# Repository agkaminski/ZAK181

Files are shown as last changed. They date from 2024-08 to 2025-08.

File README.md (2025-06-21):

# ZAK181 computer

Work in progress.

## Hardware features

- Z180 CPU,
- 1 MB of static RAM,
- 16 KB bootloader ROM,
- Comact Flash slot in True IDE mode,
- 16 bit GPIO user port,
- 2 UARTs: USB-C and RS232,
- AY-3-8912 sound,
- 80x60 8-color text mode VGA output,
- custom Cherry-MX mechanical keyboard,
- USB-C powered.

## Firmare

ZAKOS code repository is located [here](https://github.com/agkaminski/ZAKOS).

## Memory map

| Start | End | Description |
|---|---|---|
| 0x00000 | 0x03FFF | ROM, disabled after boot, after that RAM |
| 0x04000 | 0xFDFFF | RAM |
| 0xFC000 | 0xFFFFF | Memory mapped I/O, VGA VRAM |

## I/O map

8-bit I/O is used.

| Start | End  | Description |
|---|---|---|
| 0x00  | 0x3F | Z180 internal I/O |
| 0x40  | 0x5F | VBLANK IRQ acknowledge |
| 0x60  | 0x7F | ROM disable control |
| 0x80  | 0x9F | Keyboard |
| 0xA0  | 0xBF | Z80 PIO (user port) |
| 0xC0  | 0xDF | AY-3-8912 |
| 0xE0  | 0xFF | Compact Flash |

## Repository structure

### datasheet

Collection of useful datasheets, might be removed in the future.

### keyboard2

Subrepository that contains a hardware project of a mechanical keyboard for the
computer.

### kicad

KiCAD project of the computer's PCB.

### pld

Gateware of PLDs:

- [vga](pld/vga/README.md),
- [ZAK181MD](pld/ZAK181MD/README.md),
- [ZAK181AY](pld/ZAK181AY/README.md).

### schematic.pdf

[Schematic](schematic.pdf) of the computer in a friendly .pdf form.

### 3dprint

3D models designed for FDM 3D priting.

## License

[Attribution-NonCommercial 4.0](LICENSE)

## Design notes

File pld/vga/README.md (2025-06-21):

# CPLD - VGA timing generator and position counter

Target: XC95108, any speed, **not** XL version

## Pinout

| Pin | Type | Name |
|-----|---|---|
| 1 | I/O | vdata<3>  |
| 2 | I/O | vdata<4>  |
| 3 | I/O | vdata<5>  |
| 4 | I/O | vdata<6>  |
| 5 | I/O | vdata<7>  |
| 6 | I/O | vaddr<10> |
| 7 | I/O | vrd_n |
| 8 | GND | GND |
| 9 | I/O/GCK1 | pclk |
| 10  | I/O/GCK2 | TIE |
| 11  | I/O | vaddr<11> |
| 12  | I/O/GCK3 | shload_n  |
| 13  | I/O | vaddr<9>  |
| 14  | I/O | vaddr<8>  |
| 15  | I/O | vaddr<13> |
| 16  | GND | GND |
| 17  | I/O | vwr_n |
| 18  | I/O | vaddr<12> |
| 19  | I/O | vaddr<7>  |
| 20  | I/O | vaddr<6>  |
| 21  | I/O | vaddr<5>  |
| 22  | VCCIO | VCC |
| 23  | I/O | vaddr<4>  |
| 24  | I/O | vaddr<3>  |
| 25  | I/O | vaddr<2>  |
| 26  | I/O | vaddr<1>  |
| 27  | GND | GND |
| 28  | TDI | TDI |
| 29  | TMS | TMS |
| 30  | TCK | TCK |
| 31  | I/O | vaddr<0>  |
| 32  | I/O | vdata<0>  |
| 33  | I/O | vdata<2>  |
| 34  | I/O | vdata<1>  |
| 35  | I/O | scroll<0> |
| 36  | I/O | scroll<1> |
| 37  | I/O | scroll<2> |
| 38  | VCCINT | VCC |
| 39  | I/O | scroll<3> |
| 40  | I/O | scroll<4> |
| 41  | I/O | scroll<5> |
| 42  | GND | GND |
| 43  | I/O | irqack_n  |
| 44  | I/O | irq_n |
| 45  | I/O | data<3> |
| 46  | I/O | data<2> |
| 47  | I/O | data<4> |
| 48  | I/O | data<1> |
| 49  | GND | GND |
| 50  | I/O | data<5> |
| 51  | I/O | data<0> |
| 52  | I/O | data<6> |
| 53  | I/O | data<7> |
| 54  | I/O | crow<2> |
| 55  | I/O | crow<1> |
| 56  | I/O | crow<0> |
| 57  | I/O | addr<12>  |
| 58  | I/O | addr<11>  |
| 59  | TDO | TDO |
| 60  | GND | GND |
| 61  | I/O | addr<13>  |
| 62  | I/O | addr<9> |
| 63  | I/O | addr<10>  |
| 64  | VCCIO | VCC |
| 65  | I/O | addr<7> |
| 66  | I/O | addr<8> |
| 67  | I/O | addr<5> |
| 68  | I/O | addr<6> |
| 69  | I/O | addr<4> |
| 70  | I/O | addr<2> |
| 71  | I/O | addr<3> |
| 72  | I/O | addr<0> |
| 73  | VCCINT | VCC |
| 74  | I/O/GSR  | rst_n |
| 75  | I/O | addr<1> |
| 76  | I/O/GTS1 | blank |
| 77  | I/O/GTS2 | rd_n |
| 78  | VCCINT | VCC |
| 79  | I/O | wr_n |
| 80  | I/O | cs_n |
| 81  | I/O | hsync_n |
| 82  | I/O | vsync_n |
| 83  | I/O | pload_n |
| 84  | I/O | cload_n |

## vga.v

Implementation (Verilog).

## vga.dig

Test bench of sorts - uses [Digital](https://github.com/hneemann/Digital), which has a
huge advantage over plain Verilog/VHDL based test bench - it can process generated VGA
data and present it visually. It makes it a perfect tool for this kind of verification.

## vga.ucf

Pinout constraints (ISE 14.7).

## vga.jed

Bitstream ready to upload to the CPLD.

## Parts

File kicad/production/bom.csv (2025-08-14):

Designator | Footprint | Quantity | Value | LCSC Part #
C10, C11, C12, C13, C16, C22, C23, C24, C25, C26, C32, C35, C36, C4, C40, C41, C42, C44, C5, C52, C53, C56, C57, C6, C7, C70, C72, C8, C9 | C_Disc_D5.0mm_W2.5mm_P2.50mm | 29 | 100n
C27 | C_Disc_D5.0mm_W2.5mm_P2.50mm | 1 | 47n
C28, C29 | CP_Radial_D6.3mm_P2.50mm | 2 | 150u
C30, C49, C50, C51, C58 | CP_Radial_D5.0mm_P2.50mm | 5 | 10u
C33 | C_Disc_D5.0mm_W2.5mm_P2.50mm | 1 | 10n
C38, C39 | C_Disc_D5.0mm_W2.5mm_P2.50mm | 2 | 22p
C54, C55 | CP_Radial_D10.0mm_P5.00mm | 2 | 470u
C73 | C_Disc_D5.0mm_W2.5mm_P2.50mm | 1 | 100p
D1 | LED_D5.0mm | 1 | HALT
D2 | LED_D5.0mm | 1 | POWER
D3 | LED_D5.0mm | 1 | ACTIVITY
F1 | Fuse_Littelfuse_395Series | 1 | Fuse
IC1 | PLCC-68_THT-Socket | 1 | Z180
J1 | PinHeader_1x06_P2.54mm_Vertical | 1 | JTAG
J10 | DSUB-15-HD_Socket_Horizontal_P2.29x1.90mm_EdgePinOffset3.03mm_Housed_MountingHolesOffset4.94mm | 1 | DE15
J2 | DSUB-25_Socket_Horizontal_P2.77x2.84mm_EdgePinOffset7.70mm_Housed_MountingHolesOffset9.12mm | 1 | DB25_Receptacle_MountingHoles
J3 | Conn_CF_N7E50-Q516XX-40 | 1 | Compact Flash
J4 | PinHeader_1x02_P2.54mm_Vertical | 1 | Speaker
J5 | IDC-Header_2x06_P2.54mm_Vertical | 1 | Keyboard
J7 | DSUB-9_Pins_Horizontal_P2.77x2.84mm_EdgePinOffset7.70mm_Housed_MountingHolesOffset9.12mm | 1 | DSUB-9
J8 | USB_C_Receptacle_G-Switch_GT-USB-7010ASV | 1 | USB C
J9 | PinHeader_1x02_P2.54mm_Vertical | 1 | Reset
JP1 | SolderJumper-2_P1.3mm_Bridged_Pad1.0x1.5mm | 1 | Jumper_2_Bridged
LS1 | MagneticBuzzer_StarMicronics_QMB-105 | 1 | Speaker
Q2, Q3, Q4, Q5 | TO-92 | 4 | BC547
R10, R12, R13, R7, R8, R9 | R_Axial_DIN0207_L6.3mm_D2.5mm_P7.62mm_Horizontal | 6 | 3K3
R11, R14, R6 | R_Axial_DIN0207_L6.3mm_D2.5mm_P7.62mm_Horizontal | 3 | 390R
R15, R16, R20 | R_Axial_DIN0207_L6.3mm_D2.5mm_P7.62mm_Horizontal | 3 | 100R
R19, R33, R38, R39 | R_Axial_DIN0207_L6.3mm_D2.5mm_P7.62mm_Horizontal | 4 | 1K
R26, R27, R28 | R_Axial_DIN0207_L6.3mm_D2.5mm_P7.62mm_Horizontal | 3 | 2K2
R29 | R_Axial_DIN0207_L6.3mm_D2.5mm_P7.62mm_Horizontal | 1 | 10R
R30, R32 | R_Axial_DIN0207_L6.3mm_D2.5mm_P7.62mm_Horizontal | 2 | 10K
R31 | R_Axial_DIN0207_L6.3mm_D2.5mm_P7.62mm_Horizontal | 1 | 220K
R34, R35 | R_Axial_DIN0207_L6.3mm_D2.5mm_P7.62mm_Horizontal | 2 | 5K6
RN2 | R_Array_SIP9 | 1 | 47K
RN3 | R_Array_SIP5 | 1 | 1K
RV1 | Potentiometer_Vishay_T73YP_Vertical | 1 | 1K
SW1 | SW_TH_Tactile_Omron_B3F-10xx | 1 | Reset
U17 | DIP-8_W7.62mm | 1 | LM386
U18 | DIP-8_W7.62mm | 1 | NE555P
U2 | DIP-40_W15.24mm | 1 | Z80 PIO A
U20 | PLCC-84_THT-Socket | 1 | XC95108PC84
U21, U30 | DIP-20_W7.62mm | 2 | 74HC377
U22 | DIP-20_W7.62mm | 1 | 74HC244
U23 | DIP-28_W15.24mm | 1 | 27C64
U24 | DIP-16_W7.62mm | 1 | 74HC166
U25 | DIP-16_W7.62mm | 1 | MAX232
U26 | SOP-8_3.9x4.9mm_P1.27mm | 1 | CH340N
U27 | DIP-28_W15.24mm | 1 | 62256
U28, U40 | DIP-32_W15.24mm | 2 | AS6C4008
U29 | DIP-28_W15.24mm | 1 | 27C128
U3 | DIP-28_W15.24mm | 1 | AY-3-8912
U31 | DIP-20_W7.62mm | 1 | ZAK181MD (GAL16V8)
U32 | DIP-16_W7.62mm | 1 | 74HC157
U33 | DIP-20_W7.62mm | 1 | ZAK181AY (GAL16V8)
U8 | DIP-16_W7.62mm | 1 | 74HC138
X1 | Oscillator_DIP-14 | 1 | 25.175 MHz
Y2 | Crystal_HC49-4H_Vertical | 1 | 12.288 MHz

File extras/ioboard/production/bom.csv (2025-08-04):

Designator | Footprint | Quantity | Value | LCSC Part #
D1, D2, D3 | LED_D5.0mm | 3 | LED
J1, J2, J3, J4 | PinHeader_1x02_P2.54mm_Vertical | 4 | Conn_01x02
SW1 | SW_PUSH_6mm | 1 | SW_SPST

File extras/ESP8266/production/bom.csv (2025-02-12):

Designator | Footprint | Quantity | Value | LCSC Part #
C1, C2, C3 | 0805 | 3 | 10u
C4, C7 | CP_EIA-3528-15_AVX-H_Pad1.50x2.35mm_HandSolder | 2 | 22u
C5, C6 | 0805 | 2 | 100n
D1, D2 | D_MiniMELF | 2 | 1N4148
J1 | DSUB-9_Female_EdgeMount_P2.77mm | 1 | DE9_Receptacle
JP1 | SolderJumper-2_P1.3mm_Bridged_RoundedPad1.0x1.5mm | 1 | ~{CTS}
JP2 | SolderJumper-2_P1.3mm_Bridged_RoundedPad1.0x1.5mm | 1 | ~{RTS}
R1 | 0805 | 1 | 2K2
R2 | 0805 | 1 | 3K3
SW1 | SW_SPST_PTS645 | 1 | BOOT
U1 | ESP32-WROOM-32D | 1 | ESP32-WROOM-32E
U2 | SOP-16_4.4x10.4mm_P1.27mm | 1 | MAX3232
U3 | SOT-223-3_TabPin2 | 1 | AMS1117

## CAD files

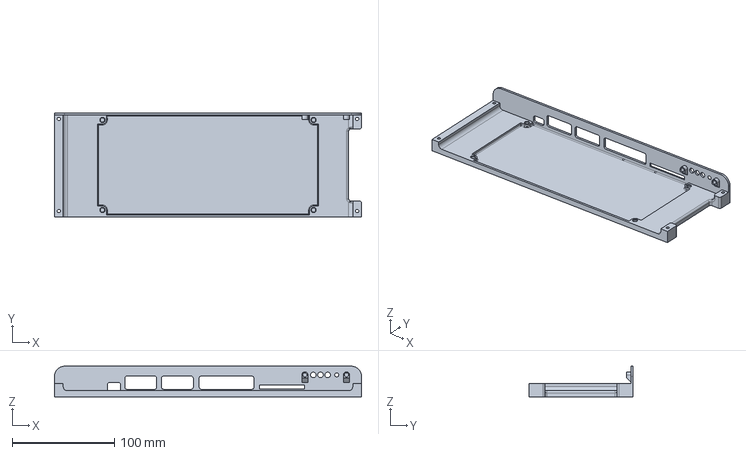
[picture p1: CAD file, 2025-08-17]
3dprint/case-debug.FCStd
300.0 x 102.0 x 30.0 mm

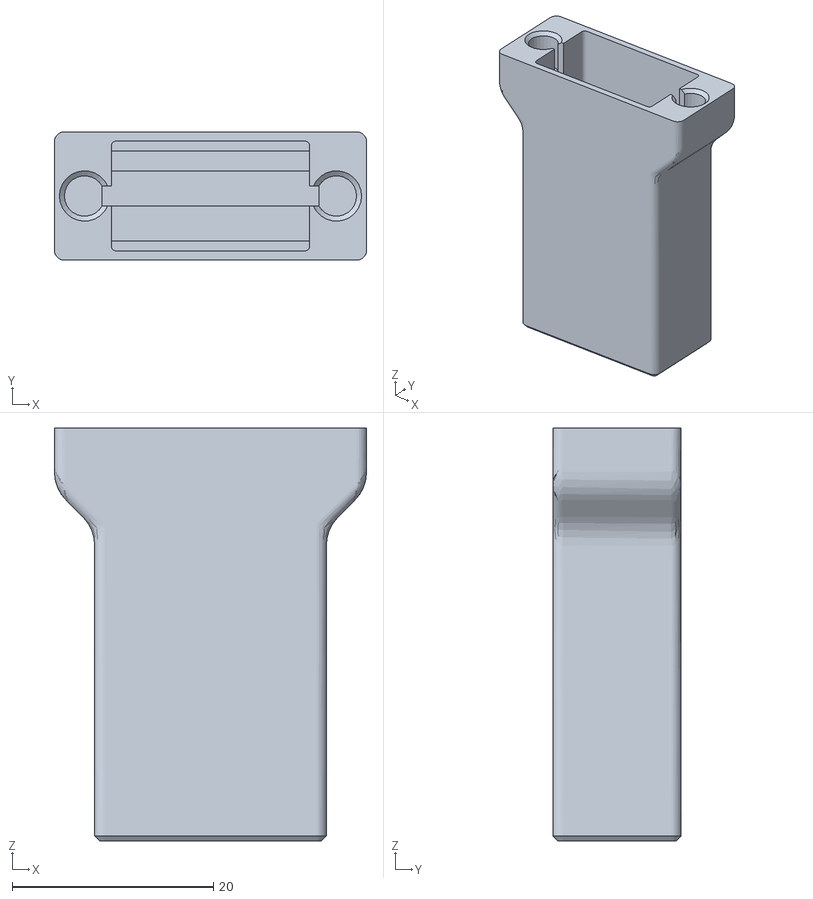
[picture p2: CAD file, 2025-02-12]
extras/ESP8266/case.stl
31.0 x 12.8 x 41.0

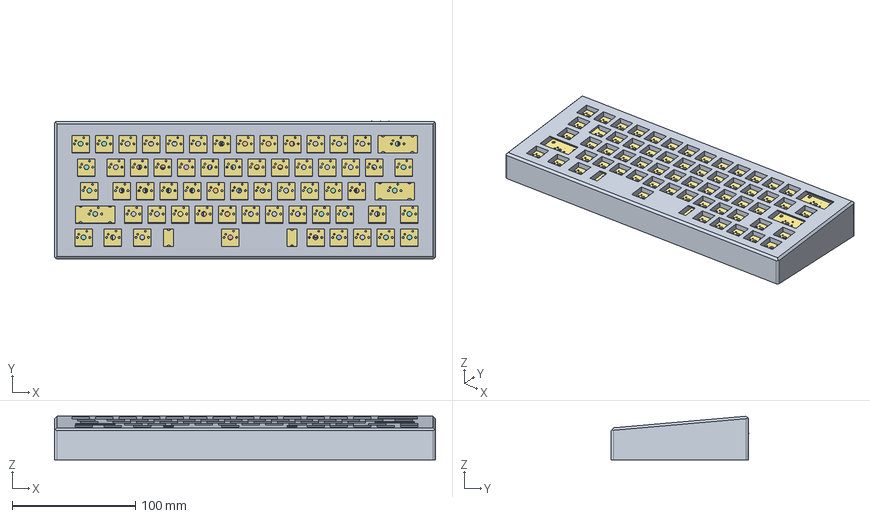
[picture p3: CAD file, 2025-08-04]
3dprint/case.FCStd
309.0 x 111.7 x 35.3 mm
Top
C_Disc_D5.0mm_W2.5mm_P2.50mm
DIP-8_W7.62mm
Crystal_HC49-4H_Vertical
C_Disc_D5.0mm_W2.5mm_P2.50mm001
R_Axial_DIN0207_L6.3mm_D2.5mm_P7.62mm_Horizontal
R_Axial_DIN0207_L6.3mm_D2.5mm_P7.62mm_Horizontal001
R_Axial_DIN0207_L6.3mm_D2.5mm_P7.62mm_Horizontal002
C_Disc_D5.0mm_W2.5mm_P2.50mm002
DIP-16_W7.62mm
R_Axial_DIN0207_L6.3mm_D2.5mm_P7.62mm_Horizontal003
DIP-32_W15.24mm
C_Disc_D5.0mm_W2.5mm_P2.50mm003
C_Disc_D5.0mm_W2.5mm_P2.50mm004
C_Disc_D5.0mm_W2.5mm_P2.50mm005
R_Axial_DIN0207_L6.3mm_D2.5mm_P7.62mm_Horizontal004
C_Disc_D5.0mm_W2.5mm_P2.50mm006
C_Disc_D5.0mm_W2.5mm_P2.50mm007
TO-92
CP_Radial_D10.0mm_P5.00mm
CP_Radial_D5.0mm_P2.50mm
C_Disc_D5.0mm_W2.5mm_P2.50mm008
R_Axial_DIN0207_L6.3mm_D2.5mm_P7.62mm_Horizontal005
C_Disc_D5.0mm_W2.5mm_P2.50mm009
DIP-16_W7.62mm001
LED_D5.0mm
C_Disc_D5.0mm_W2.5mm_P2.50mm010
C_Disc_D5.0mm_W2.5mm_P2.50mm011
R_Array_SIP9
DIP-16_W7.62mm002
DIP-28_W15.24mm
C_Disc_D5.0mm_W2.5mm_P2.50mm012
DSUB-9_Pins_Horizontal_P2.77x2.84mm_EdgePinOffset9.90mm_Housed_MountingHolesOffset11.32mm
DSUB-25_Socket_Horizontal_P2.77x2.84mm_EdgePinOffset9.90mm_Housed_MountingHolesOffset11.32mm
C_Disc_D5.0mm_W2.5mm_P2.50mm013
DIP-20_W7.62mm
R_Axial_DIN0207_L6.3mm_D2.5mm_P7.62mm_Horizontal006
C_Disc_D5.0mm_W2.5mm_P2.50mm014
C_Disc_D5.0mm_W2.5mm_P2.50mm015
C_Disc_D5.0mm_W2.5mm_P2.50mm016
DIP-20_W7.62mm001
DIP-28_W15.24mm001
C_Disc_D5.0mm_W2.5mm_P2.50mm017
PinHeader_1x02_P2.54mm_Vertical
DIP-28_W15.24mm002
DIP-28_W15.24mm003
Oscillator_DIP-14
R_Axial_DIN0207_L6.3mm_D2.5mm_P7.62mm_Horizontal007
R_Axial_DIN0207_L6.3mm_D2.5mm_P7.62mm_Horizontal008
DIP-40_W15.24mm
LED_D5.0mm001
C_Disc_D5.0mm_W2.5mm_P2.50mm018
C_Disc_D5.0mm_W2.5mm_P2.50mm019
C_Disc_D5.0mm_W2.5mm_P2.50mm020
CP_Radial_D6.3mm_P2.50mm
C_Disc_D5.0mm_W2.5mm_P2.50mm021
TO-093
CP_Radial_D5.0mm_P2.50mm001
R_Array_SIP5
C_Disc_D5.0mm_W2.5mm_P2.50mm022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

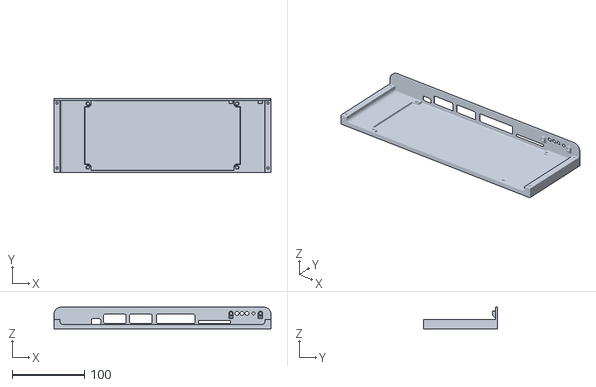
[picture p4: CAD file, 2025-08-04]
3dprint/case-Bottom.stl
300.0 x 102.0 x 30.0

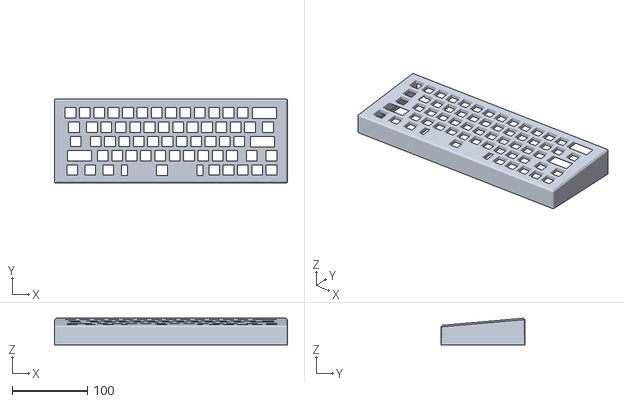
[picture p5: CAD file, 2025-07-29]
3dprint/case-Top.stl
309.0 x 111.5 x 35.3

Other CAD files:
3dprint/case-Bottom-debug.stl

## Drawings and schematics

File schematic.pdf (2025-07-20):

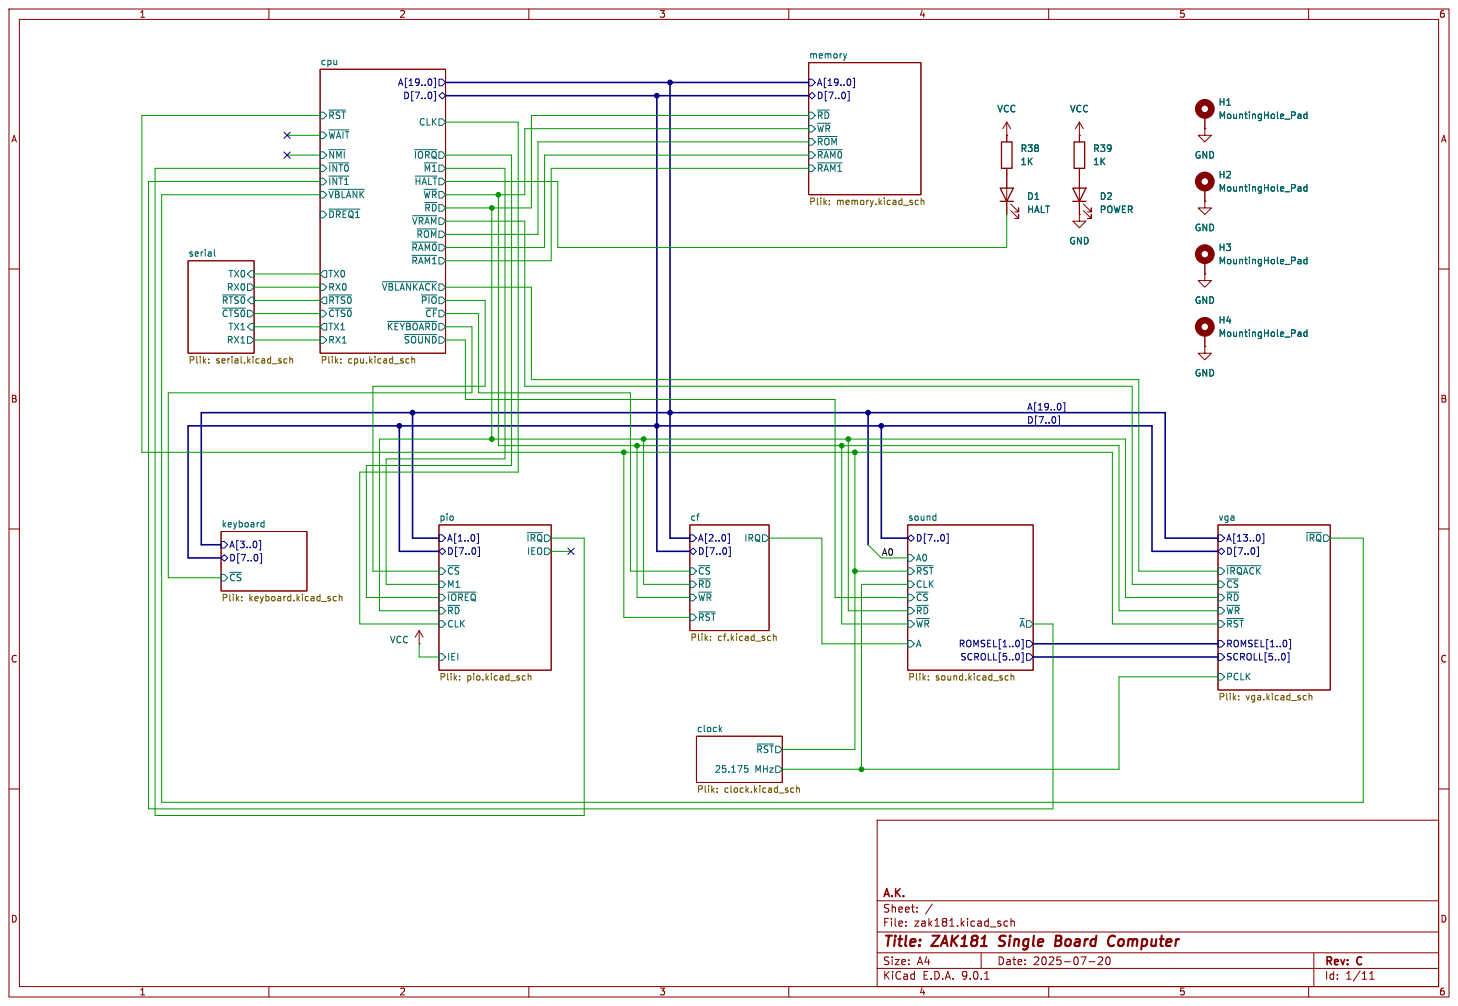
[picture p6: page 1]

~{CF} cpu Plik: cpu.kicad_sch

~{IRQACK} vga Plik: vga.kicad_sch

Id: 1/11 Title: ZAK181 Single Board Computer File: zak181.kicad_sch Sheet: / A.K. ~{RST} 25.175 MHz

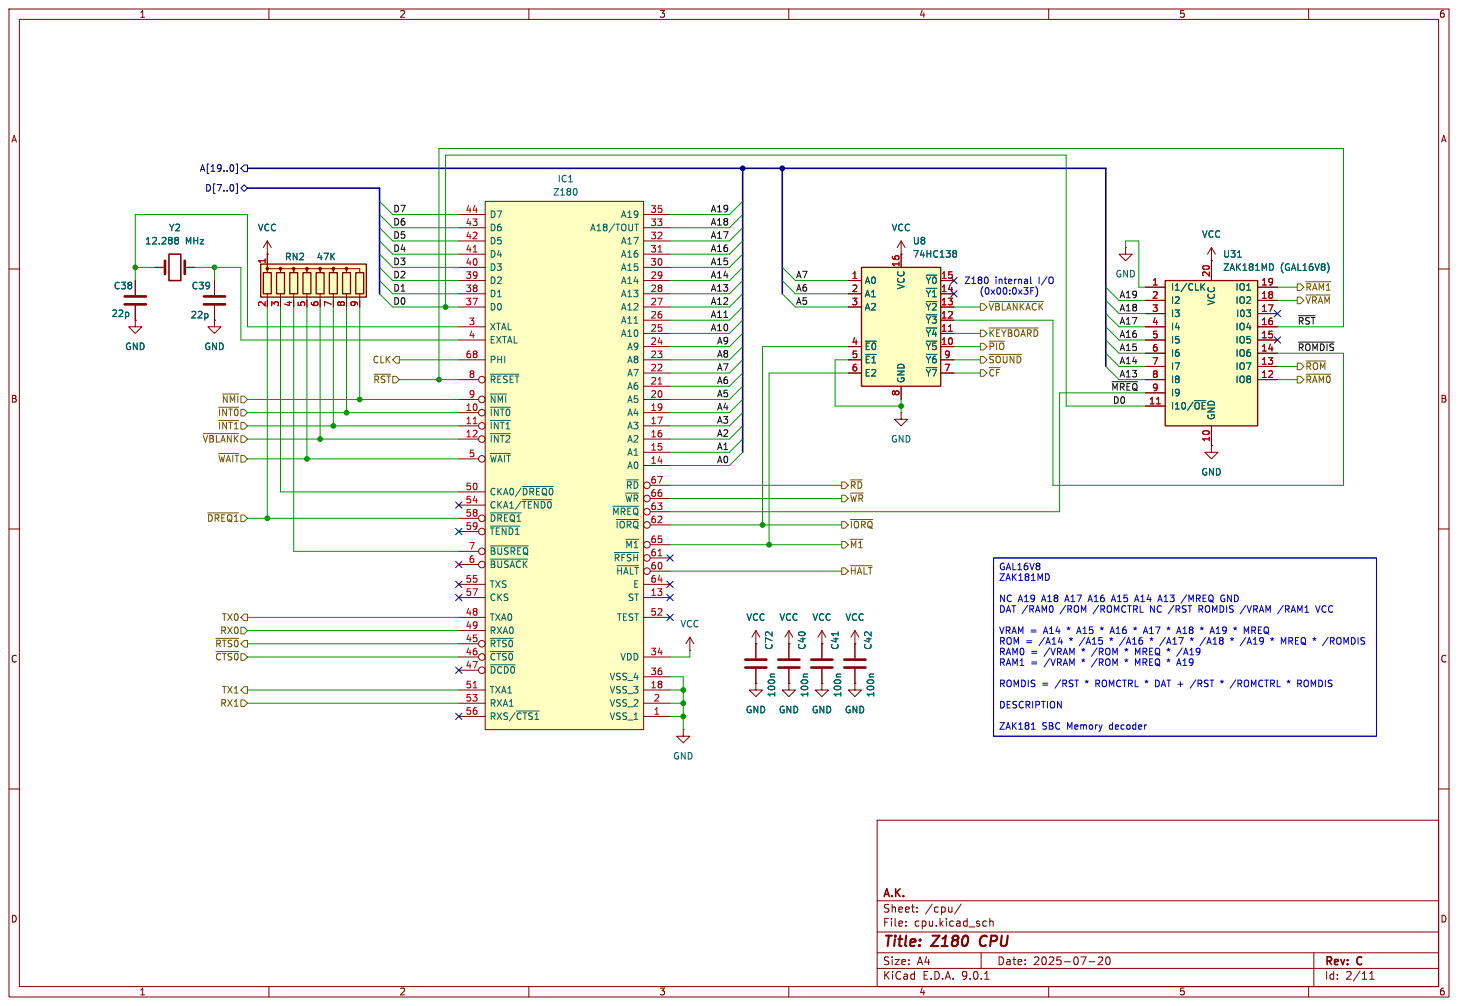
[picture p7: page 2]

NC A19 A18 A17 A16 A15 A14 A13 /MREQ GND
DAT /RAM0 /ROM /ROMCTRL NC /RST ROMDIS /VRAM /RAM1 VCC

VRAM = A14 * A15 * A16 * A17 * A18 * A19 * MREQ
ROM = /A14 * /A15 * /A16 * /A17 * /A18 * /A19 * MREQ * /ROMDIS RAM0 = /VRAM * /ROM * MREQ * /A19 RAM1 = /VRAM * /ROM * MREQ * A19 ROMDIS = /RST * ROMCTRL * DAT + /RST * /ROMCTRL * ROMDIS DESCRIPTION

File: cpu.kicad_sch Sheet: /cpu/ A.K.

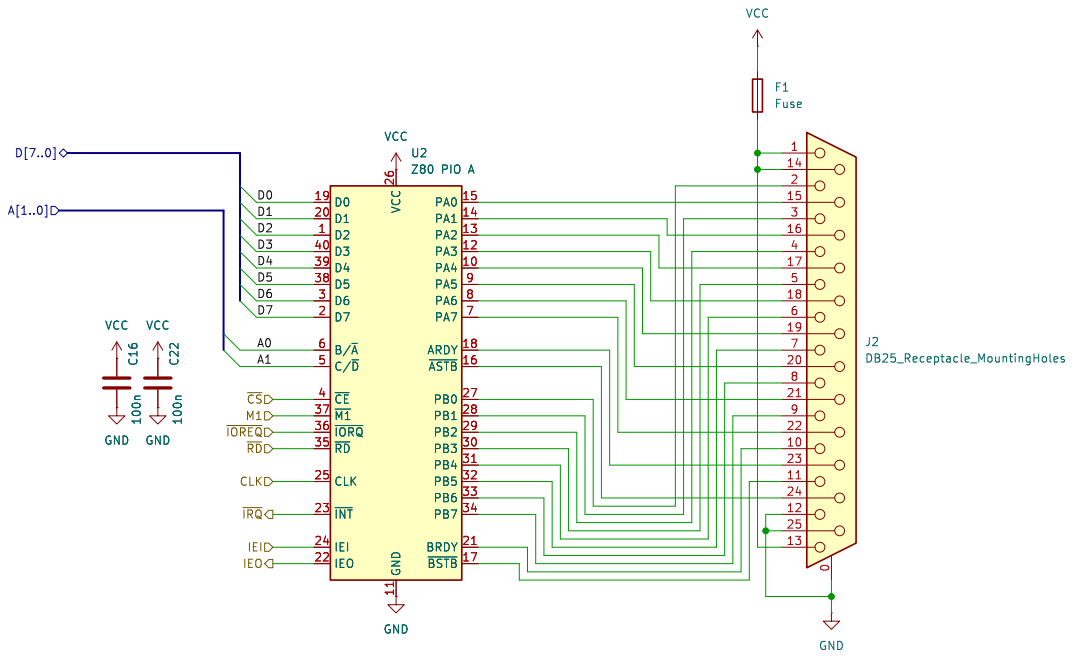
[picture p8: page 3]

Id: 5/11 Title: User port File: pio.kicad_sch Sheet: /pio/ A.K.

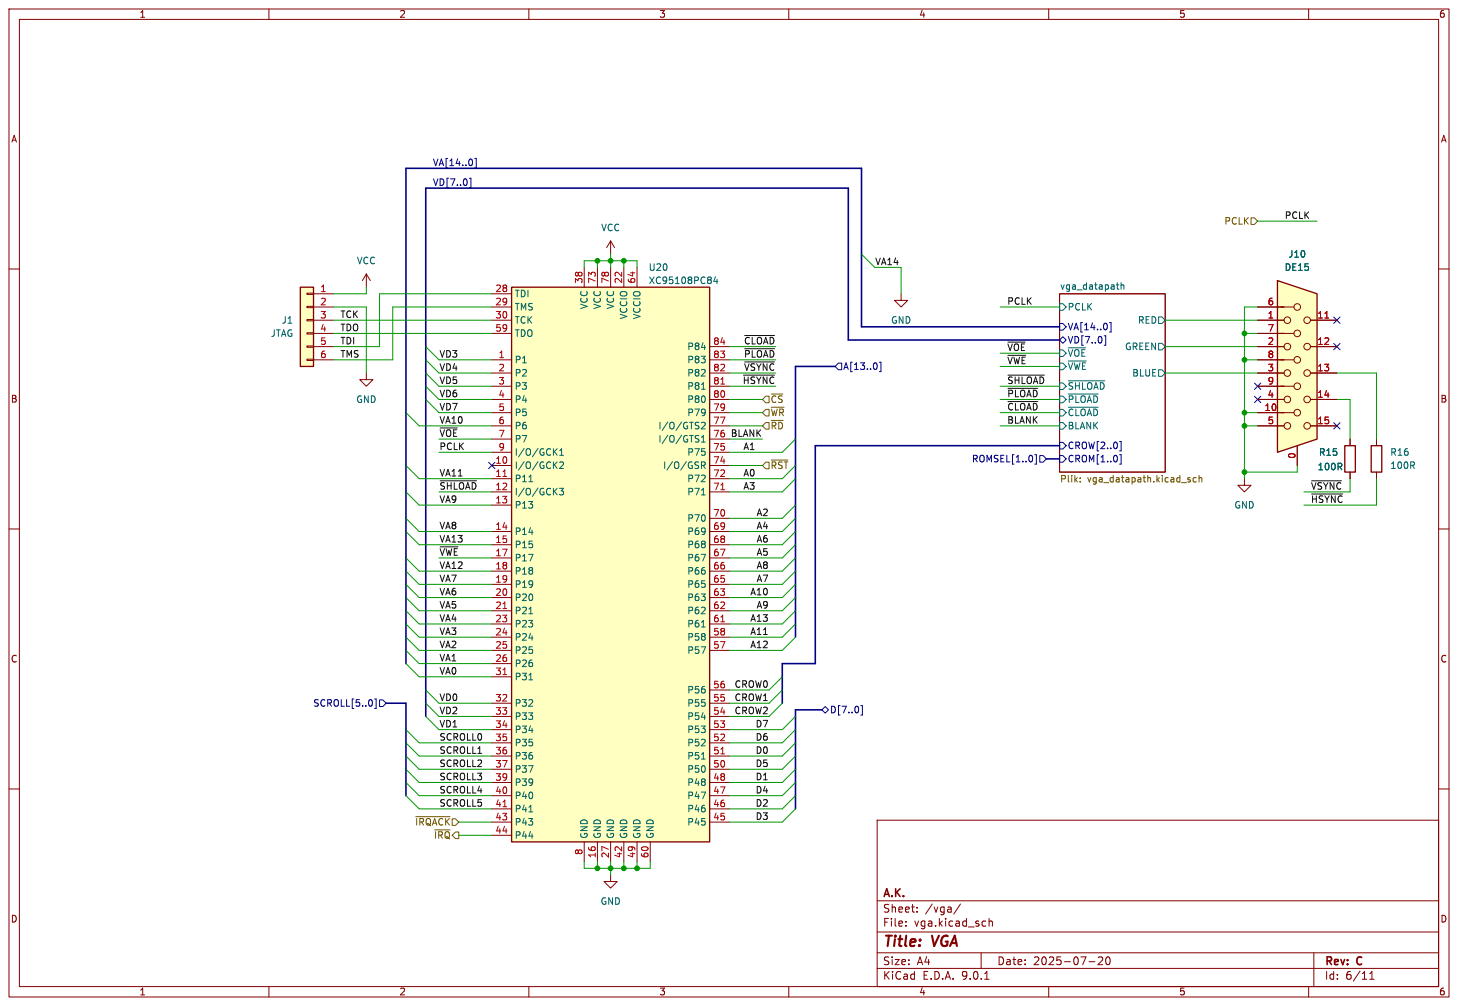
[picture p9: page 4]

File: vga.kicad_sch Sheet: /vga/ A.K.

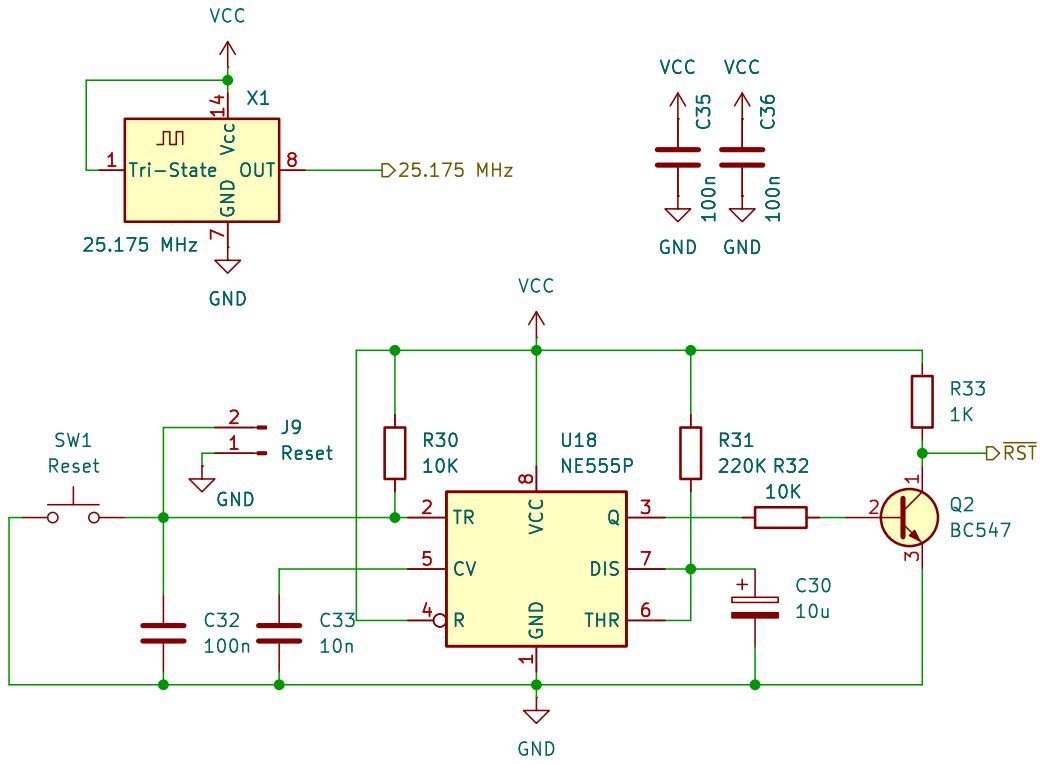
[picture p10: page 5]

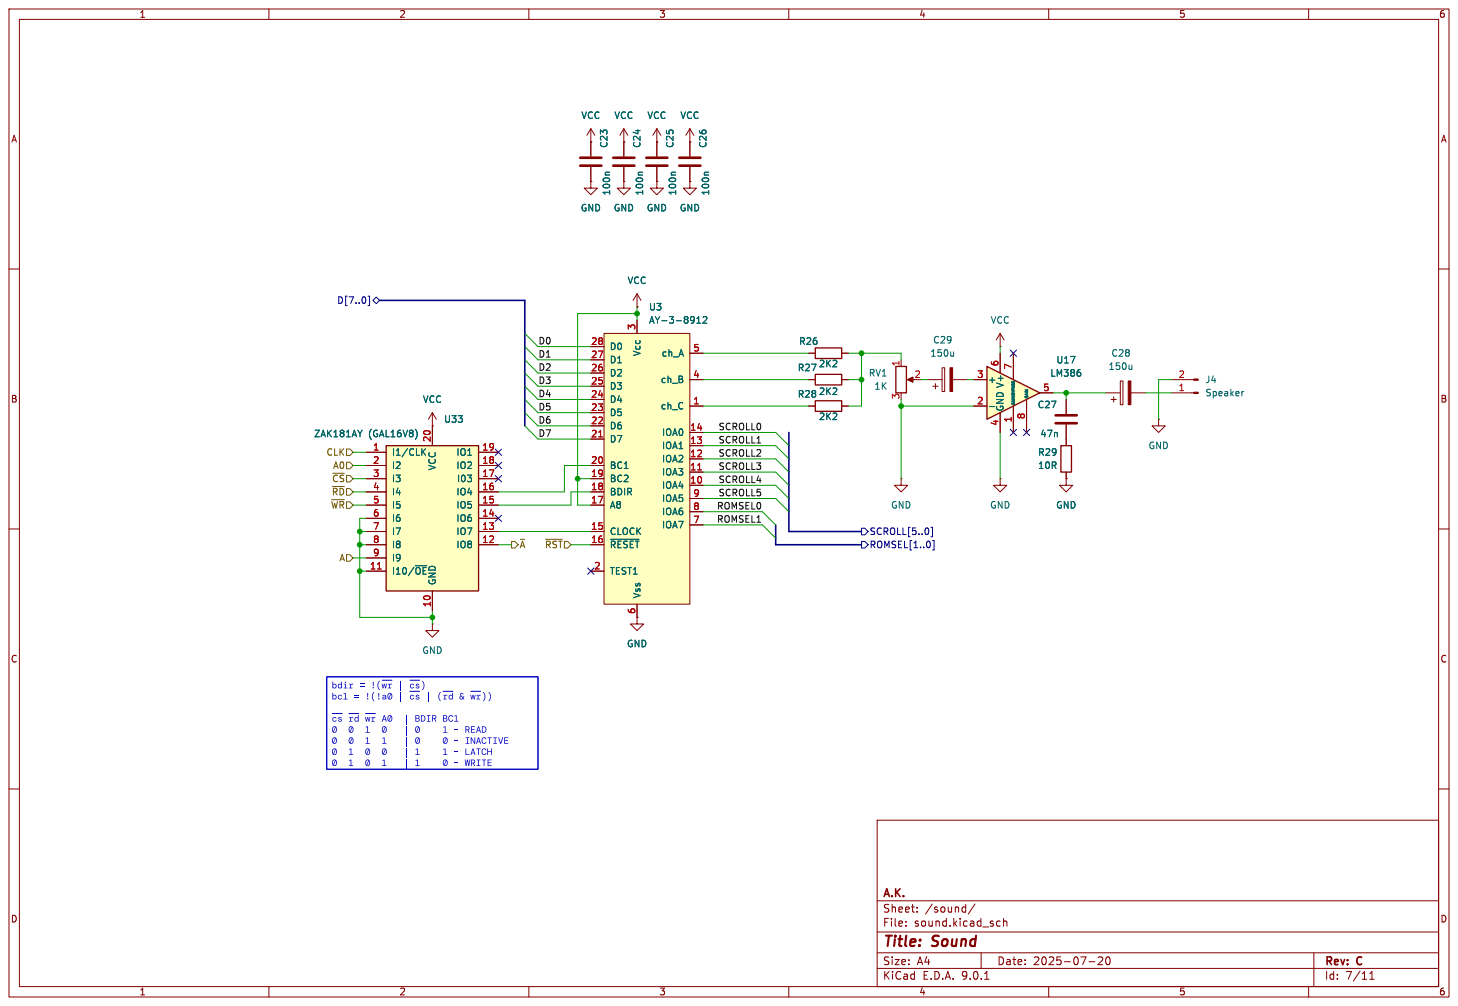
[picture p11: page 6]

5 VCC C23 100n VCC GND C24 100n GND

~{cs}~{rd}~{wr}A0 | BDIR BC1

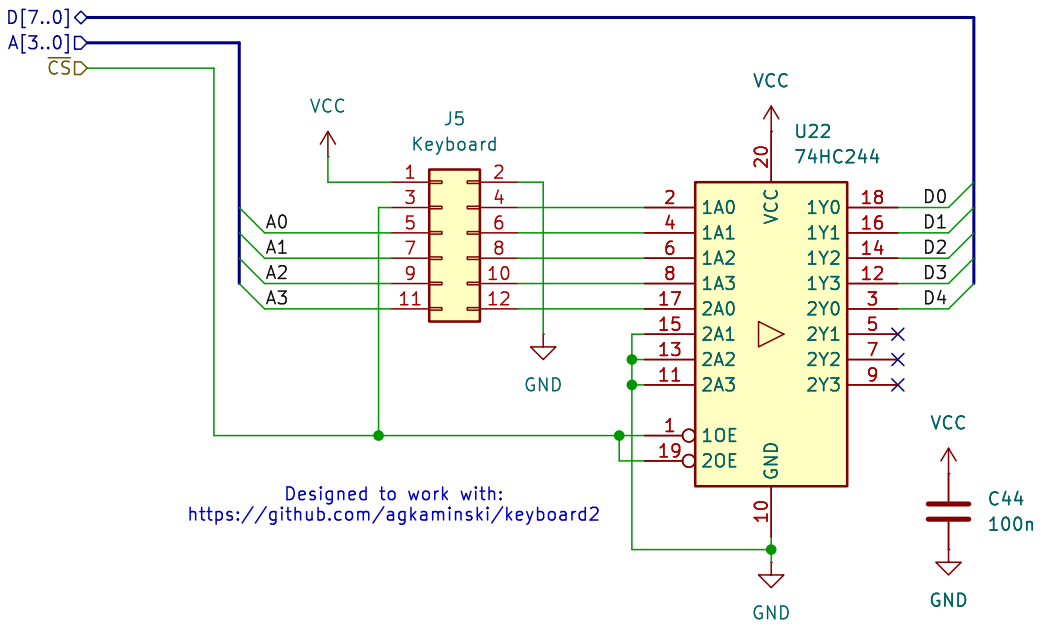
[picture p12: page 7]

10 | 1A3 8
12

File: keyboard.kicad_sch Sheet: /keyboard/ A.K.

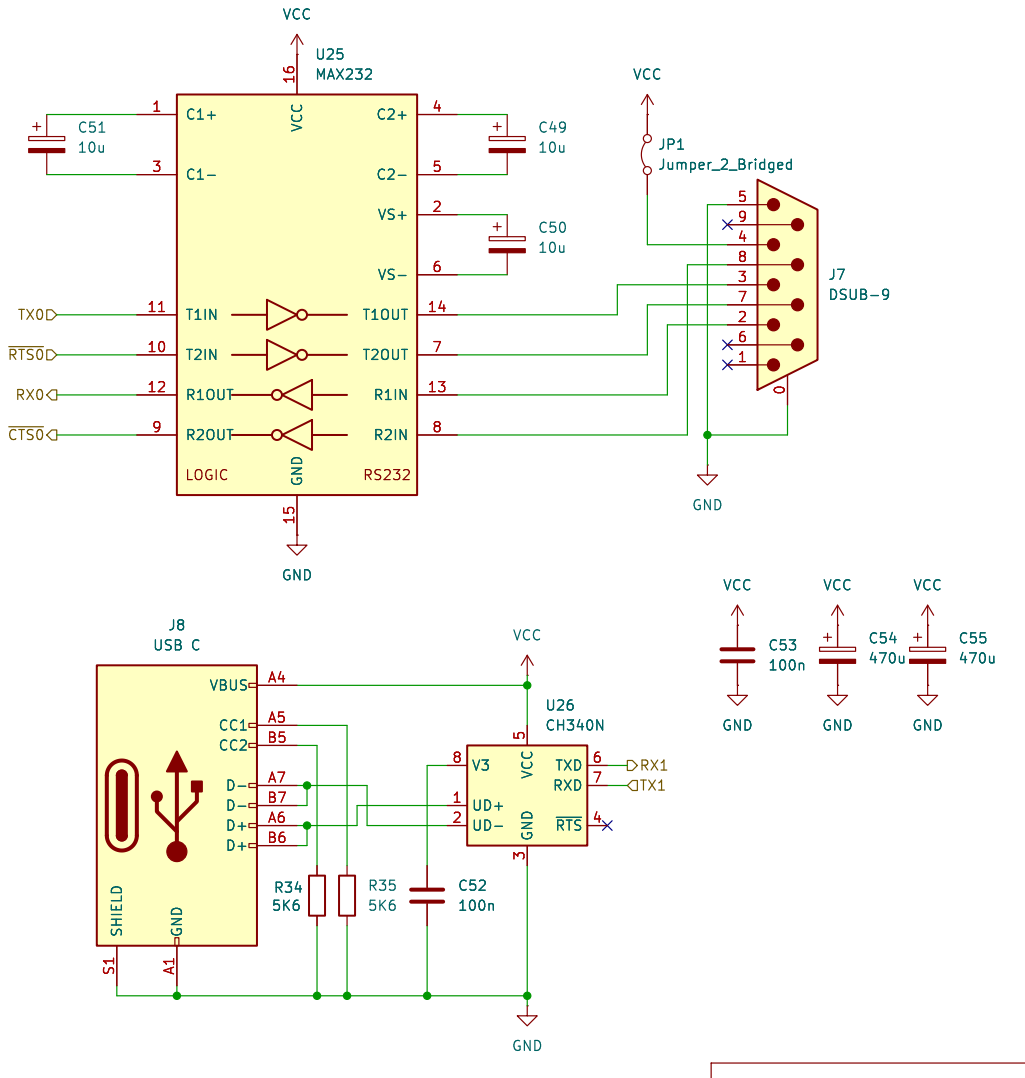
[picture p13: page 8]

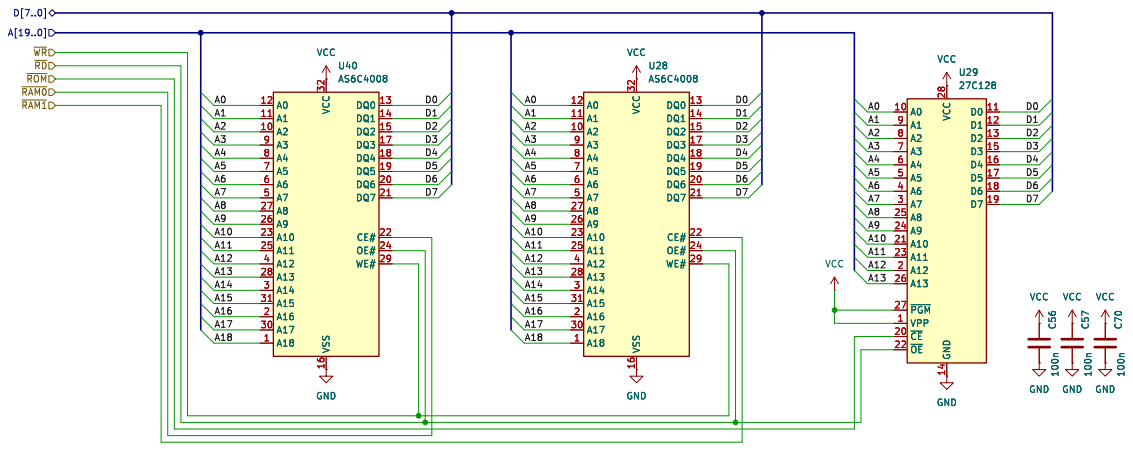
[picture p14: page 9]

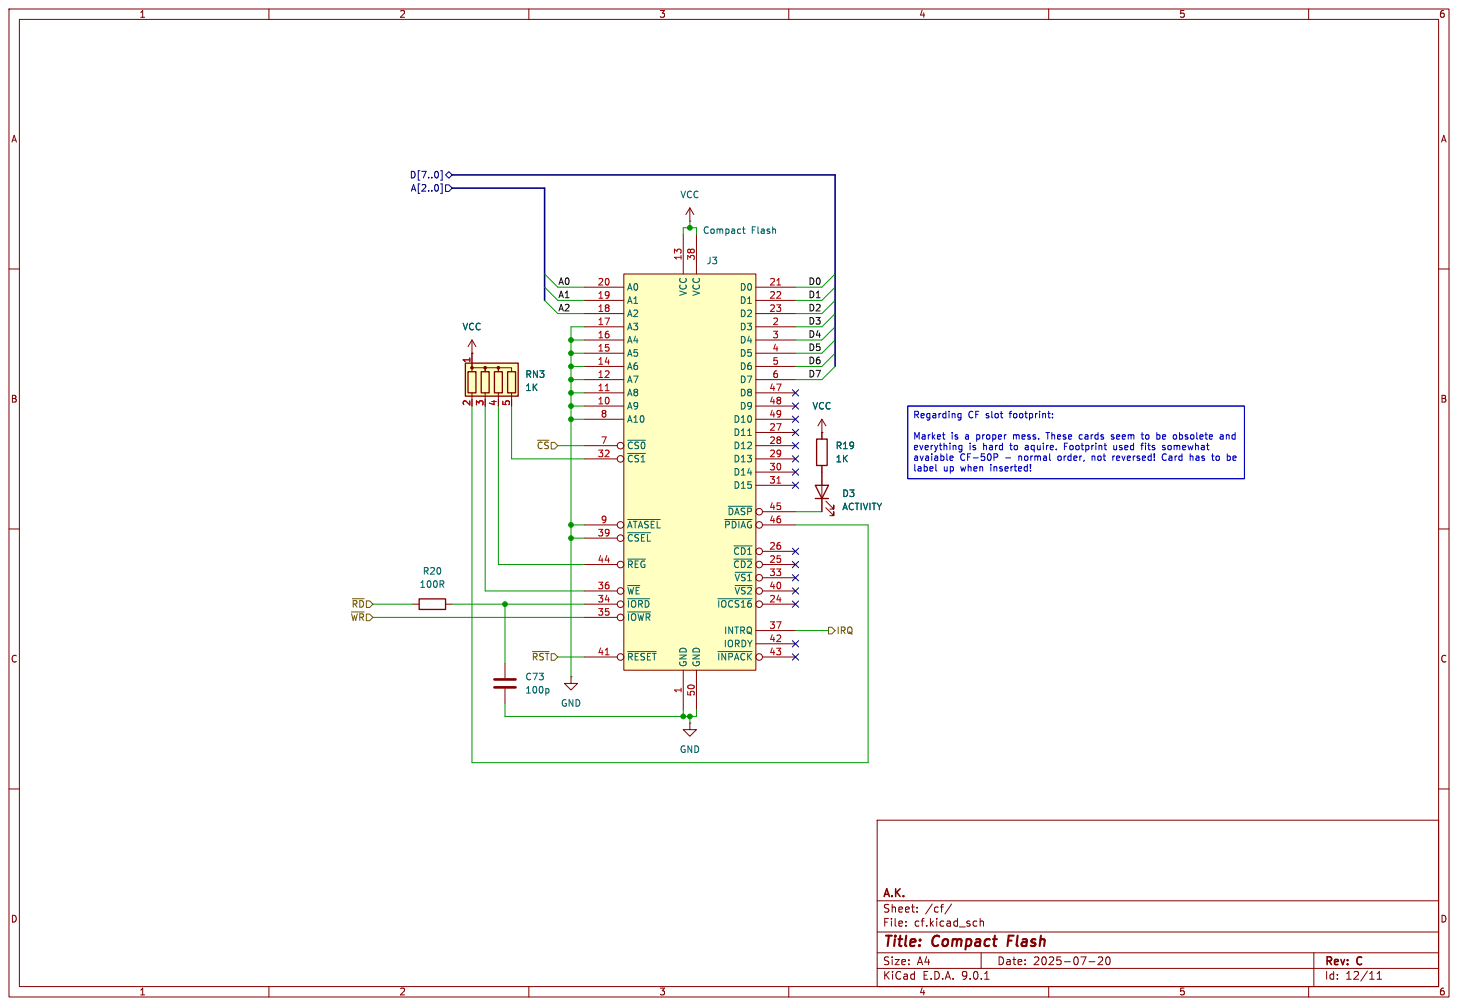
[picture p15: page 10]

1 VCC 38 GND 50 D0 21 D1 22 D2 23 D3 2 D4 3 D5 4 D6 5 D7 6 D8 47 D9 48 D10 49 D11 27 D12 28 D13 29 D14 30 D15 31 ~{DASP} 45 ~{PDIAG} 46 ~{CD1} 26 ~{CD2} 25 ~{VS1} 33 ~{VS2} 40 ~{IOCS16} 24

label up when inserted! VCC

Id: 12/11 Title: Compact Flash

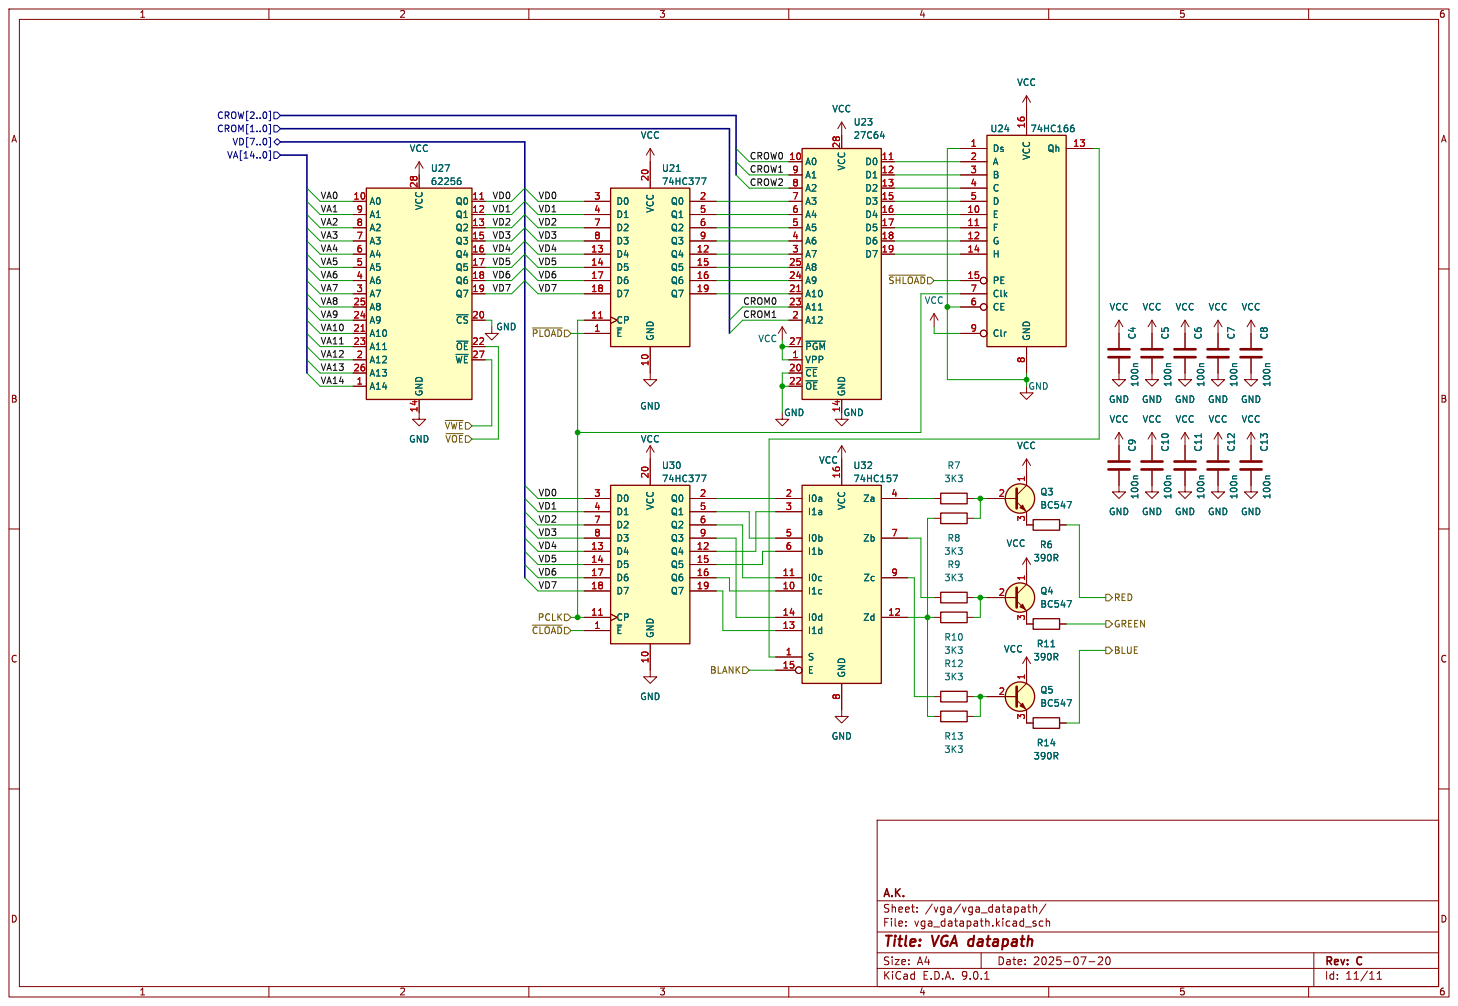
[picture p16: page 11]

Id: 11/11 Title: VGA datapath

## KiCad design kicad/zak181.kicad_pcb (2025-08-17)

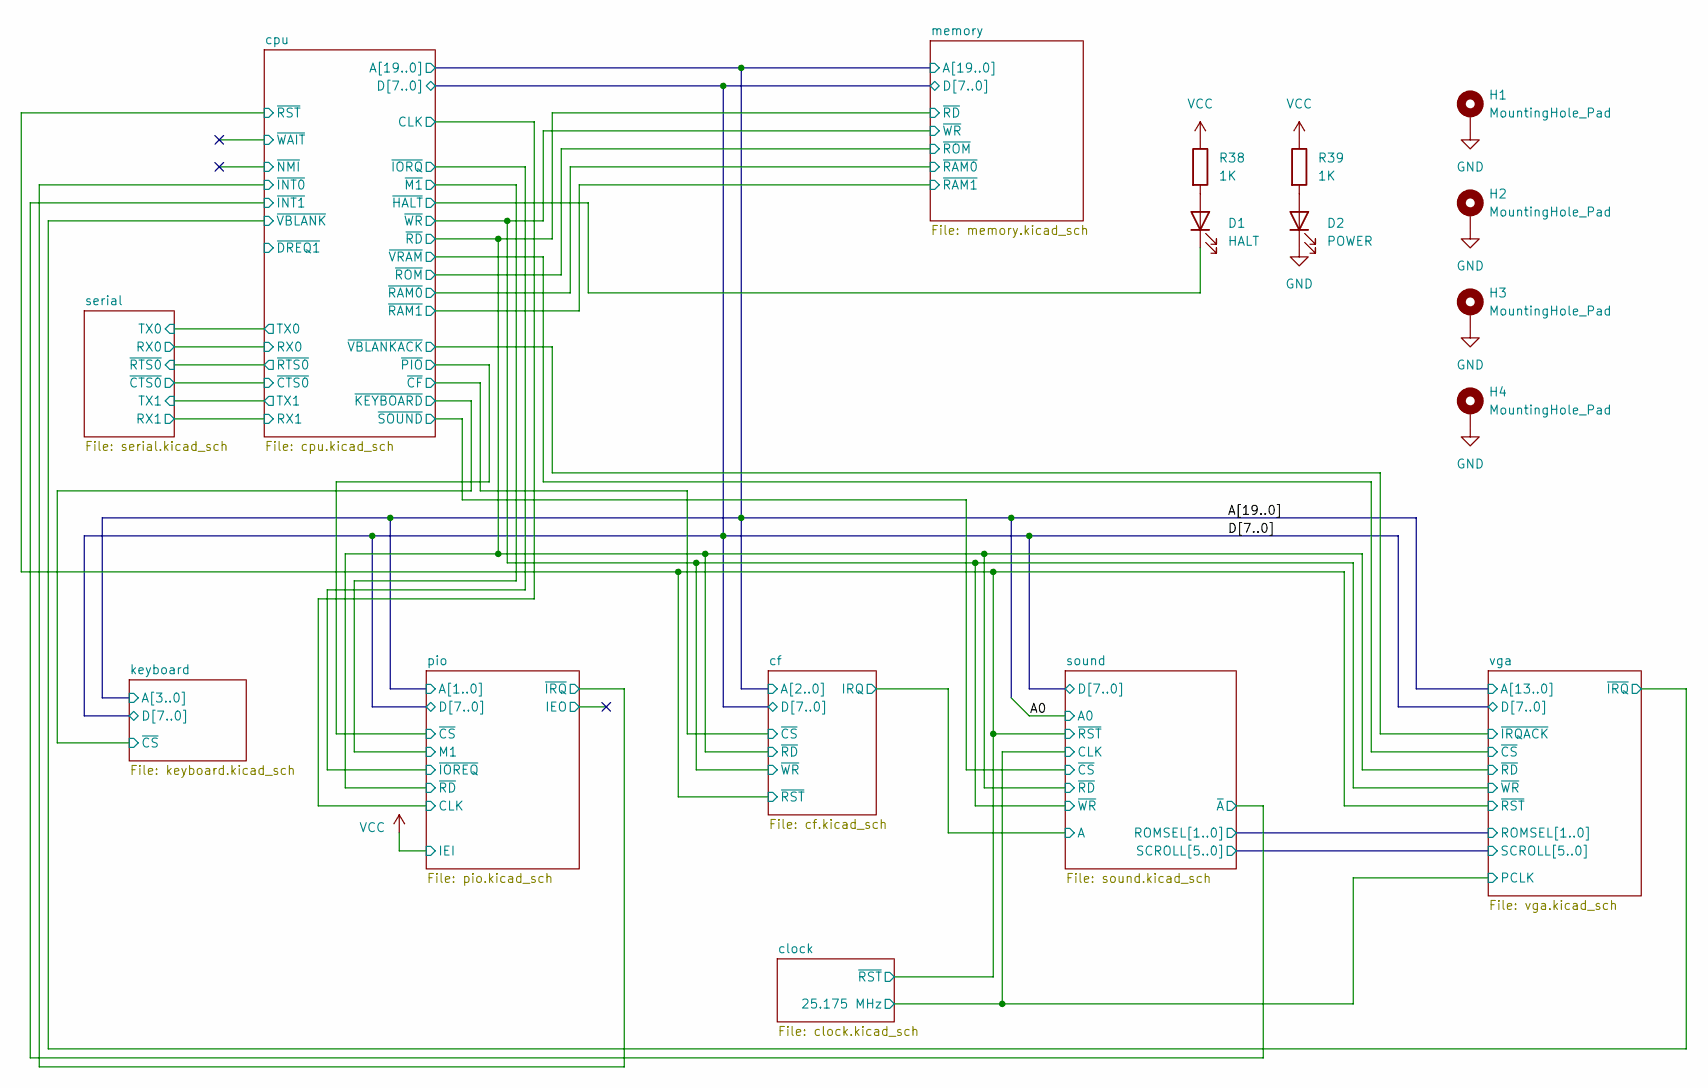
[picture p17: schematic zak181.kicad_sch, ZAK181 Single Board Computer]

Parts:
D1: HALT; LED_D5.0mm
D2: POWER; LED_D5.0mm
H1, H2, H3, H4: MountingHole_Pad; MountingHole_3.2mm_M3_Pad_Via
R38, R39: 1K; R_Axial_DIN0207_L6.3mm_D2.5mm_P7.62mm_Horizontal

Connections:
/cpu/~HALT: D1.1 (K); also elsewhere on the board
GND: D2.1 (K), H1.1, H2.1, H3.1, H4.1; also elsewhere on the board
unnamed: D1.2 (A), R38.2
unnamed: D2.2 (A), R39.2
VCC: R38.1, R39.1; also elsewhere on the board

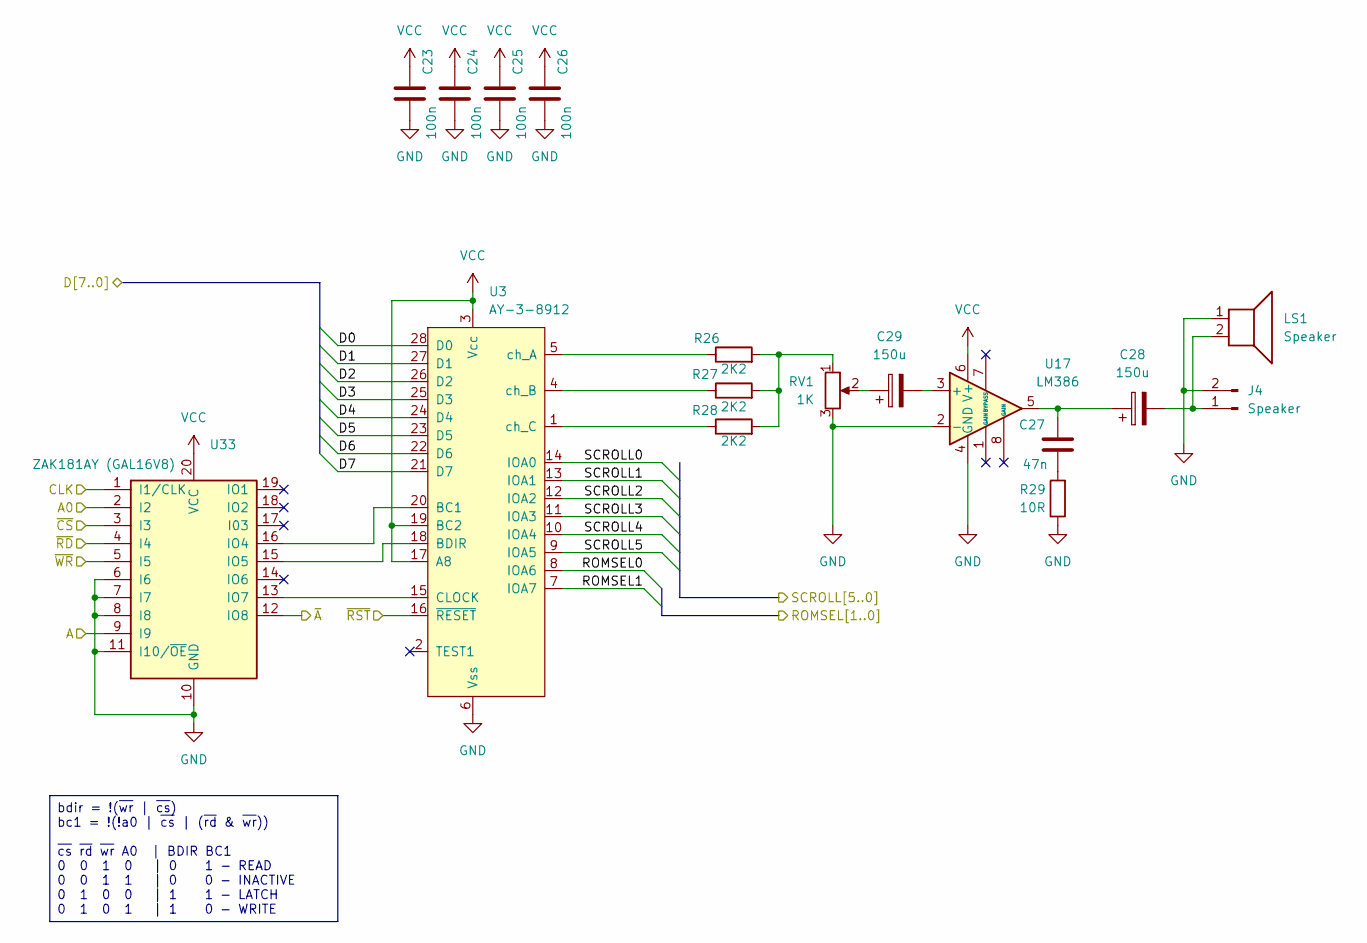
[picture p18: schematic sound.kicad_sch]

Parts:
C23, C24, C25, C26: 100n; C_Disc_D5.0mm_W2.5mm_P2.50mm
C27: 47n; C_Disc_D5.0mm_W2.5mm_P2.50mm
C28, C29: 150u; CP_Radial_D6.3mm_P2.50mm
J4: Speaker; PinHeader_1x02_P2.54mm_Vertical
LS1: Speaker; MagneticBuzzer_StarMicronics_QMB-105
R26, R27, R28: 2K2; R_Axial_DIN0207_L6.3mm_D2.5mm_P7.62mm_Horizontal
R29: 10R; R_Axial_DIN0207_L6.3mm_D2.5mm_P7.62mm_Horizontal
RV1: 1K; Potentiometer_Vishay_T73YP_Vertical
U3: AY-3-8912; DIP-28_W15.24mm
U17: LM386; DIP-8_W7.62mm
U33: ZAK181AY (GAL16V8); DIP-20_W7.62mm

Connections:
/A0: U33.2 (I2); also elsewhere on the board
/D0: U3.28 (D0); also elsewhere on the board
/D1: U3.27 (D1); also elsewhere on the board
/D2: U3.26 (D2); also elsewhere on the board
/D3: U3.25 (D3); also elsewhere on the board
/D4: U3.24 (D4); also elsewhere on the board
/D5: U3.23 (D5); also elsewhere on the board
/D6: U3.22 (D6); also elsewhere on the board
/D7: U3.21 (D7); also elsewhere on the board
/cf/IRQ: U33.9 (I9); also elsewhere on the board
/cf/~RD: U33.4 (I4); also elsewhere on the board
/cf/~WR: U33.5 (I5); also elsewhere on the board
/cpu/~INT1: U33.12 (IO8); also elsewhere on the board
/cpu/~RST: U3.16 (~RESET); also elsewhere on the board
/cpu/~SOUND: U33.3 (I3); also elsewhere on the board
/sound/ROMSEL0: U3.8 (IOA6); also elsewhere on the board
/sound/ROMSEL1: U3.7 (IOA7); also elsewhere on the board
/sound/SCROLL0: U3.14 (IOA0); also elsewhere on the board
/sound/SCROLL1: U3.13 (IOA1); also elsewhere on the board
/sound/SCROLL2: U3.12 (IOA2); also elsewhere on the board
/sound/SCROLL3: U3.11 (IOA3); also elsewhere on the board
/sound/SCROLL4: U3.10 (IOA4); also elsewhere on the board
/sound/SCROLL5: U3.9 (IOA5); also elsewhere on the board
/vga/PCLK: U33.1 (I1/CLK); also elsewhere on the board
GND: C23.2, C24.2, C25.2, C26.2, J4.2, LS1.1, R29.1, RV1.3, U3.6 (Vss), U17.2 (-), U17.4 (GND), U33.6 (I6), U33.7 (I7), U33.8 (I8), U33.10 (GND), U33.11 (I10/~OE); also elsewhere on the board
unnamed: C27.1, C28.1, U17.5
unnamed: C27.2, R29.2
unnamed: C29.1, RV1.2
unnamed: C28.2, J4.1, LS1.2
unnamed: R26.2, R27.2, R28.2, RV1.1
unnamed: U3.20 (BC1), U33.16 (IO4)
unnamed: U3.18 (BDIR), U33.15 (IO5)
unnamed: U3.15 (CLOCK), U33.13 (IO7)
unnamed: R26.1, U3.5 (ch_A)
unnamed: R27.1, U3.4 (ch_B)
unnamed: R28.1, U3.1 (ch_C)
unnamed: C29.2, U17.3 (+)
VCC: C23.1, C24.1, C25.1, C26.1, U3.3 (Vcc), U3.17 (A8), U3.19 (BC2), U17.6 (V+), U33.20 (VCC); also elsewhere on the board

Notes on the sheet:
bdir = !(~{wr} | ~{cs}) bc1 = !(!a0 | ~{cs} | (~{rd} & ~{wr})) ~{cs} ~{rd} ~{wr} A0 | BDIR BC1 0 0 1 0 | 0 1 - READ 0 0 1 1 | 0 0 - INACTIVE 0 1 0 0 | 1 1 - LATCH 0 1 0 1 | 1 0 - WRITE

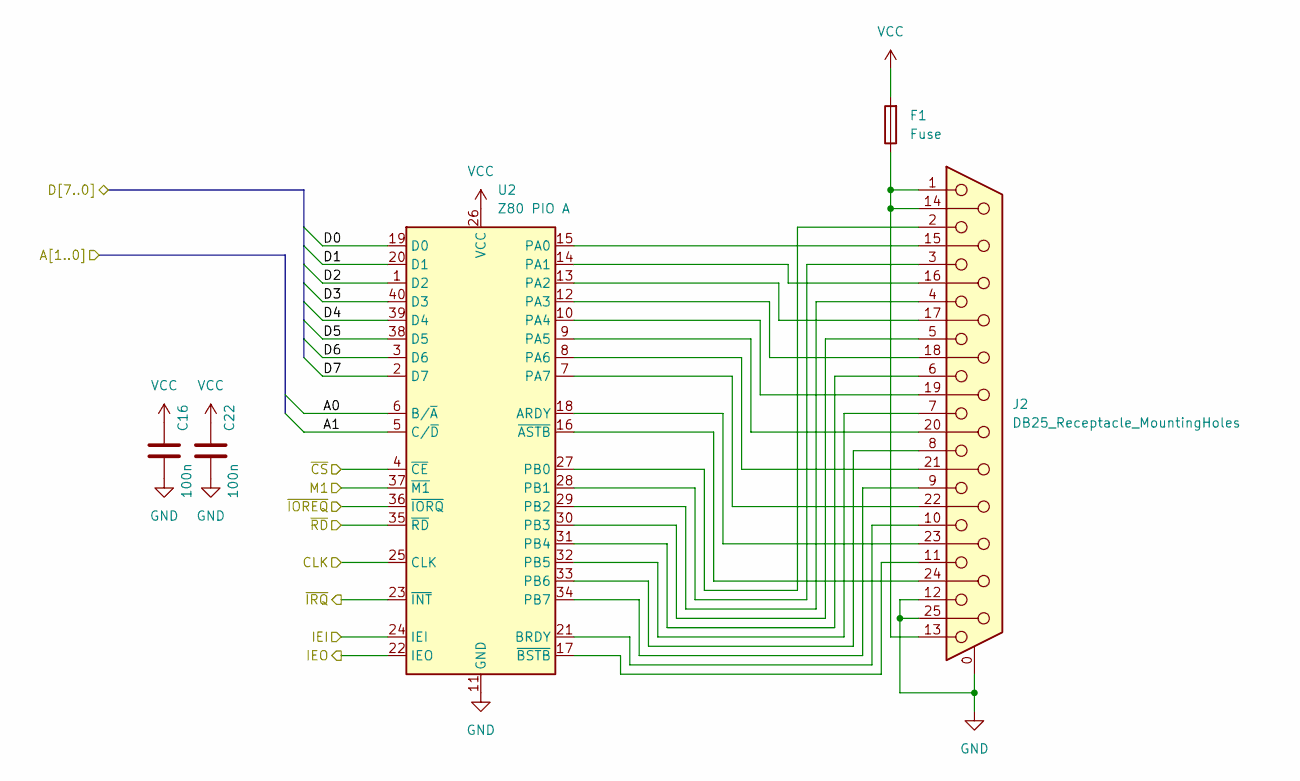
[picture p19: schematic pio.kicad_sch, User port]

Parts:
C16, C22: 100n; C_Disc_D5.0mm_W2.5mm_P2.50mm
F1: Fuse; Fuse_Littelfuse_395Series
J2: DB25_Receptacle_MountingHoles; DSUB-25_Socket_Horizontal_P2.77x2.84mm_EdgePinOffset7.70mm_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
U2: Z80 PIO A; DIP-40_W15.24mm

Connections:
/A0: U2.6 (B/~A); also elsewhere on the board
/A1: U2.5 (C/~D); also elsewhere on the board
/D0: U2.19 (D0); also elsewhere on the board
/D1: U2.20 (D1); also elsewhere on the board
/D2: U2.1 (D2); also elsewhere on the board
/D3: U2.40 (D3); also elsewhere on the board
/D4: U2.39 (D4); also elsewhere on the board
/D5: U2.38 (D5); also elsewhere on the board
/D6: U2.3 (D6); also elsewhere on the board
/D7: U2.2 (D7); also elsewhere on the board
/cf/~RD: U2.35 (~RD); also elsewhere on the board
/cpu/CLK: U2.25 (CLK); also elsewhere on the board
/cpu/~INT0: U2.23 (~INT); also elsewhere on the board
/cpu/~IORQ: U2.36 (~IORQ); also elsewhere on the board
/cpu/~M1: U2.37 (~M1); also elsewhere on the board
/cpu/~PIO: U2.4 (~CE); also elsewhere on the board
/pio/IEO: U2.22 (IEO)
GND: C16.2, C22.2, J2.0 (PAD), J2.12, J2.25, U2.11 (GND); also elsewhere on the board
unnamed: F1.1, J2.1, J2.13, J2.14
unnamed: J2.15, U2.15 (PA0)
unnamed: J2.16, U2.14 (PA1)
unnamed: J2.17, U2.13 (PA2)
unnamed: J2.18, U2.12 (PA3)
unnamed: J2.19, U2.10 (PA4)
unnamed: J2.20, U2.9 (PA5)
unnamed: J2.21, U2.8 (PA6)
unnamed: J2.22, U2.7 (PA7)
unnamed: J2.23, U2.18 (ARDY)
unnamed: J2.24, U2.16 (~ASTB)
unnamed: J2.10, U2.21 (BRDY)
unnamed: J2.2, U2.27 (PB0)
unnamed: J2.3, U2.28 (PB1)
unnamed: J2.4, U2.29 (PB2)
unnamed: J2.5, U2.30 (PB3)
unnamed: J2.6, U2.31 (PB4)
unnamed: J2.7, U2.32 (PB5)
unnamed: J2.8, U2.33 (PB6)
unnamed: J2.9, U2.34 (PB7)
unnamed: J2.11, U2.17 (~BSTB)
VCC: C16.1, C22.1, F1.2, U2.24 (IEI), U2.26 (VCC); also elsewhere on the board

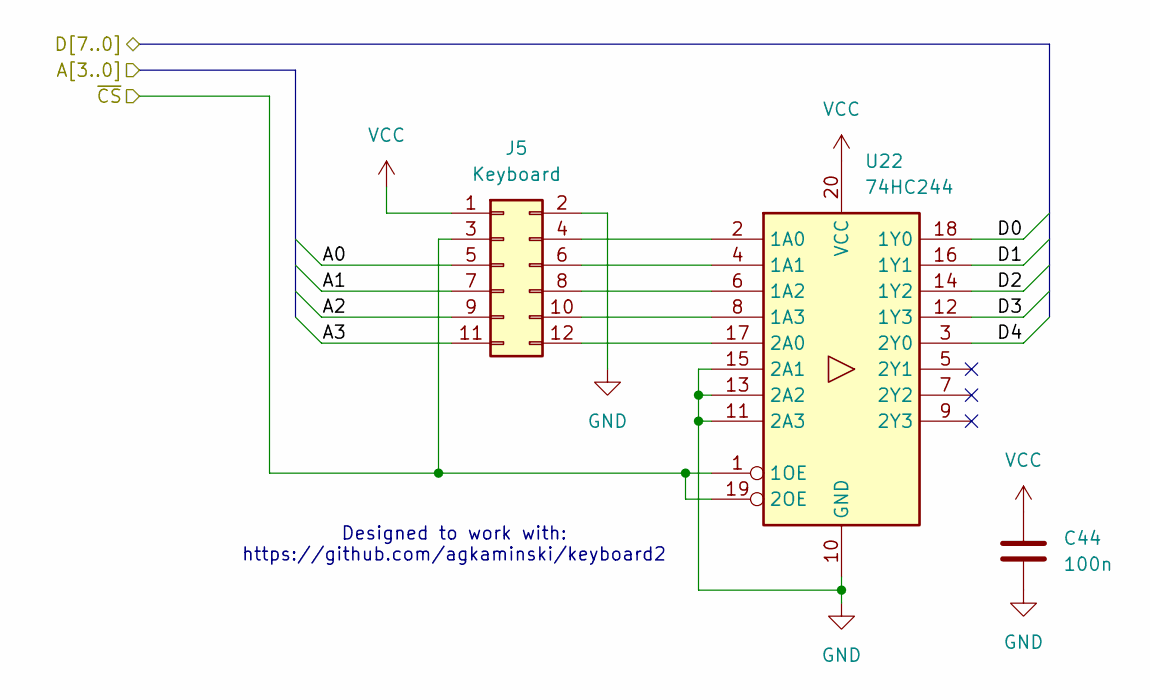
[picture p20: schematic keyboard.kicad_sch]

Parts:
C44: 100n; C_Disc_D5.0mm_W2.5mm_P2.50mm
J5: Keyboard; IDC-Header_2x06_P2.54mm_Vertical
U22: 74HC244; DIP-20_W7.62mm

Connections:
/A0: J5.5; also elsewhere on the board
/A1: J5.7; also elsewhere on the board
/A2: J5.9; also elsewhere on the board
/A3: J5.11; also elsewhere on the board
/D0: U22.18 (1Y0); also elsewhere on the board
/D1: U22.16 (1Y1); also elsewhere on the board
/D2: U22.14 (1Y2); also elsewhere on the board
/D3: U22.12 (1Y3); also elsewhere on the board
/D4: U22.3 (2Y0); also elsewhere on the board
/cpu/~KEYBOARD: J5.3, U22.1 (1OE), U22.19 (2OE); also elsewhere on the board
GND: C44.2, J5.2, U22.10 (GND), U22.11 (2A3), U22.13 (2A2), U22.15 (2A1); also elsewhere on the board
unnamed: J5.4, U22.2 (1A0)
unnamed: J5.6, U22.4 (1A1)
unnamed: J5.8, U22.6 (1A2)
unnamed: J5.10, U22.8 (1A3)
unnamed: J5.12, U22.17 (2A0)
VCC: C44.1, J5.1, U22.20 (VCC); also elsewhere on the board

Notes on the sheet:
Designed to work with: https://github.com/agkaminski/keyboard2

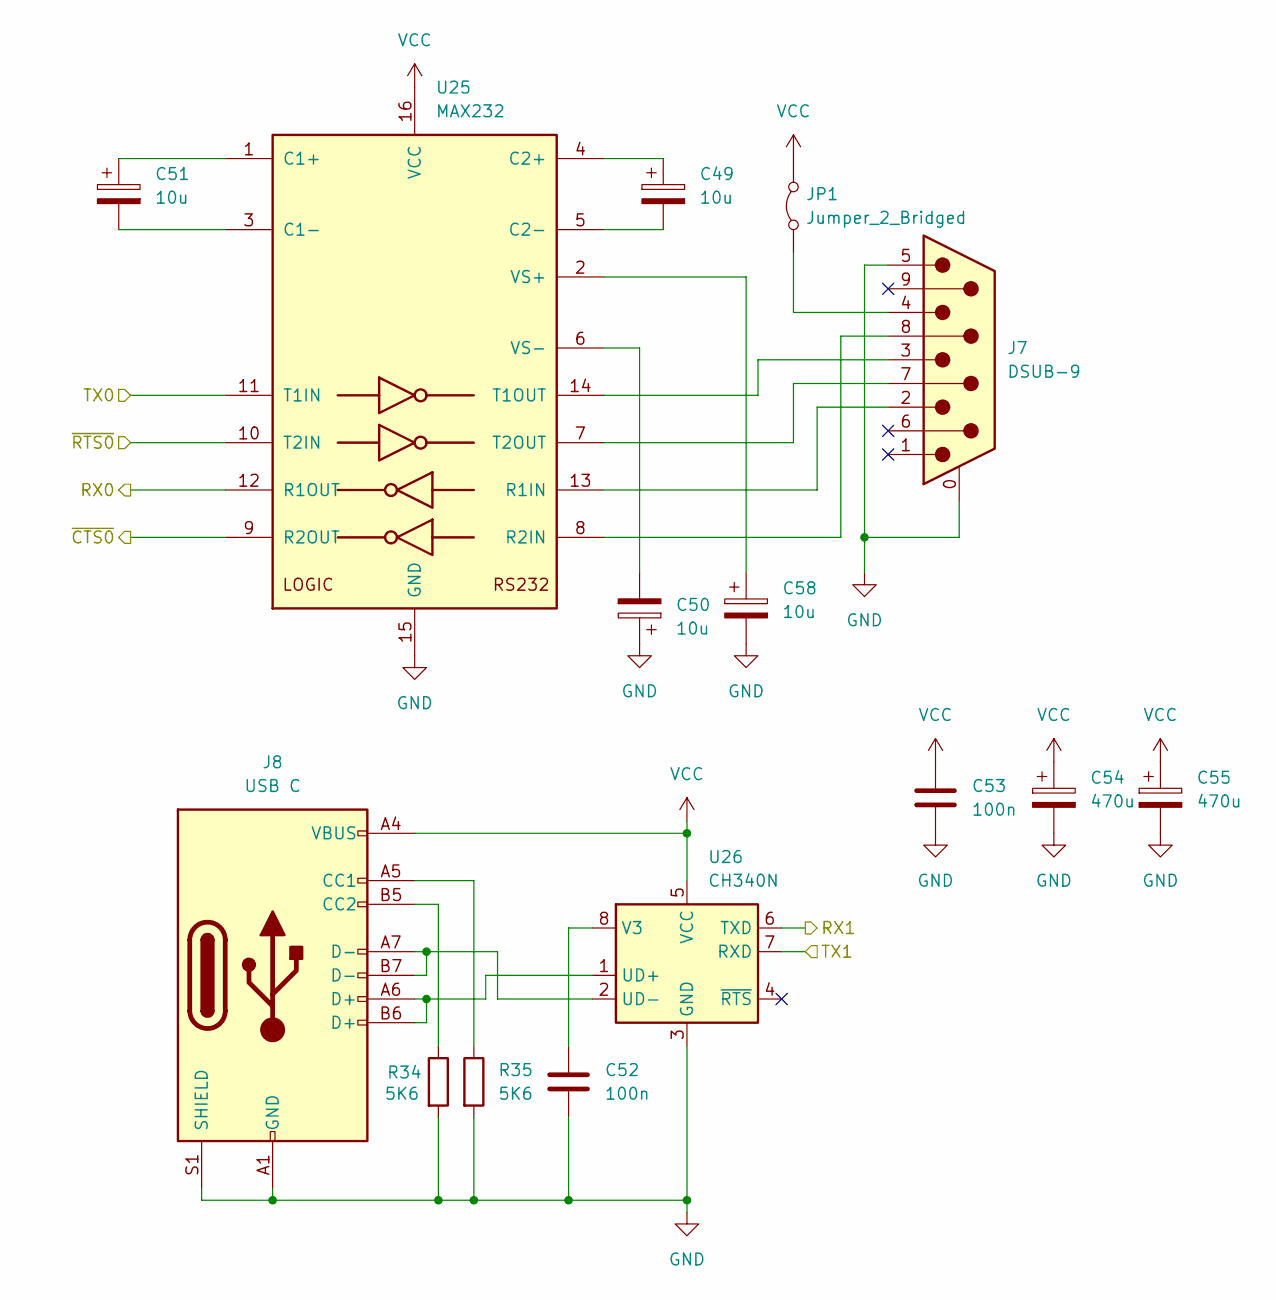
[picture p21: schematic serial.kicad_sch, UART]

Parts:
C49, C50, C51, C58: 10u; CP_Radial_D5.0mm_P2.50mm
C52, C53: 100n; C_Disc_D5.0mm_W2.5mm_P2.50mm
C54, C55: 470u; CP_Radial_D10.0mm_P5.00mm
J7: DSUB-9; DSUB-9_Pins_Horizontal_P2.77x2.84mm_EdgePinOffset7.70mm_Hou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
J8: USB C; USB_C_Receptacle_G-Switch_GT-USB-7010ASV
JP1: Jumper_2_Bridged; SolderJumper-2_P1.3mm_Bridged_Pad1.0x1.5mm
R34, R35: 5K6; R_Axial_DIN0207_L6.3mm_D2.5mm_P7.62mm_Horizontal
U25: MAX232; DIP-16_W7.62mm
U26: CH340N; SOP-8_3.9x4.9mm_P1.27mm

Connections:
/cpu/RX0: U25.12 (R1OUT); also elsewhere on the board
/cpu/RX1: U26.6 (TXD); also elsewhere on the board
/cpu/TX0: U25.11 (T1IN); also elsewhere on the board
/cpu/TX1: U26.7 (RXD); also elsewhere on the board
/cpu/~CTS0: U25.9 (R2OUT); also elsewhere on the board
/cpu/~RTS0: U25.10 (T2IN); also elsewhere on the board
GND: C50.1, C52.2, C53.2, C54.2, C55.2, C58.2, J7.0 (PAD), J7.5, J8.A1 (GND), J8.A12 (GND), J8.B1 (GND), J8.B12 (GND), J8.S1 (SHIELD), R34.2, R35.2, U25.15 (GND), U26.3 (GND); also elsewhere on the board
unnamed: J8.A5 (CC1), R35.1
unnamed: J8.B5 (CC2), R34.1
unnamed: J7.4, JP1.1 (A)
unnamed: C51.1, U25.1 (C1+)
unnamed: C51.2, U25.3 (C1-)
unnamed: C49.1, U25.4 (C2+)
unnamed: C49.2, U25.5 (C2-)
unnamed: J7.2, U25.13 (R1IN)
unnamed: J7.8, U25.8 (R2IN)
unnamed: J7.3, U25.14 (T1OUT)
unnamed: J7.7, U25.7 (T2OUT)
unnamed: C58.1, U25.2 (VS+)
unnamed: C50.2, U25.6 (VS-)
unnamed: J8.A6 (D+), J8.B6 (D+), U26.1 (UD+)
unnamed: J8.A7 (D-), J8.B7 (D-), U26.2 (UD-)
unnamed: C52.1, U26.8 (V3)
VCC: C53.1, C54.1, C55.1, J8.A4 (VBUS), J8.A9 (VBUS), J8.B4 (VBUS), J8.B9 (VBUS), JP1.2 (B), U25.16 (VCC), U26.5 (VCC); also elsewhere on the board

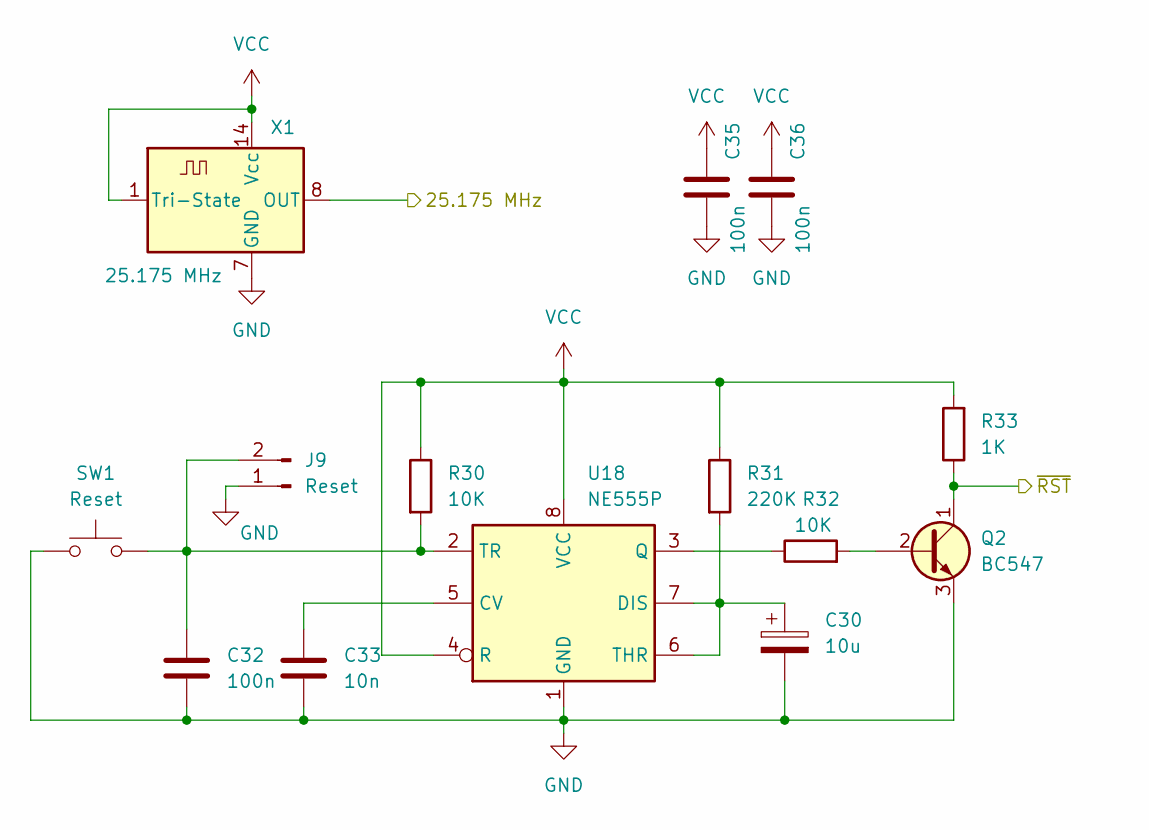
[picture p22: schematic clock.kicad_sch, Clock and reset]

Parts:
C30: 10u; CP_Radial_D5.0mm_P2.50mm
C32, C35, C36: 100n; C_Disc_D5.0mm_W2.5mm_P2.50mm
C33: 10n; C_Disc_D5.0mm_W2.5mm_P2.50mm
J9: Reset; PinHeader_1x02_P2.54mm_Vertical
Q2: BC547; TO-92
R30, R32: 10K; R_Axial_DIN0207_L6.3mm_D2.5mm_P7.62mm_Horizontal
R31: 220K; R_Axial_DIN0207_L6.3mm_D2.5mm_P7.62mm_Horizontal
R33: 1K; R_Axial_DIN0207_L6.3mm_D2.5mm_P7.62mm_Horizontal
SW1: Reset; SW_TH_Tactile_Omron_B3F-10xx
U18: NE555P; DIP-8_W7.62mm
X1: 25.175 MHz; Oscillator_DIP-14

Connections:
/cpu/~RST: Q2.1 (C), R33.1; also elsewhere on the board
/vga/PCLK: X1.8 (OUT); also elsewhere on the board
GND: C30.2, C32.2, C33.2, C35.2, C36.2, J9.1, Q2.3 (E), SW1.1, U18.1 (GND), X1.7 (GND); also elsewhere on the board
unnamed: C32.1, J9.2, R30.2, SW1.2, U18.2 (TR)
unnamed: Q2.2 (B), R32.2
unnamed: C33.1, U18.5 (CV)
unnamed: C30.1, R31.2, U18.6 (THR), U18.7 (DIS)
unnamed: R32.1, U18.3 (Q)
VCC: C35.1, C36.1, R30.1, R31.1, R33.2, U18.4 (R), U18.8 (VCC), X1.1 (Tri-State), X1.14 (Vcc); also elsewhere on the board

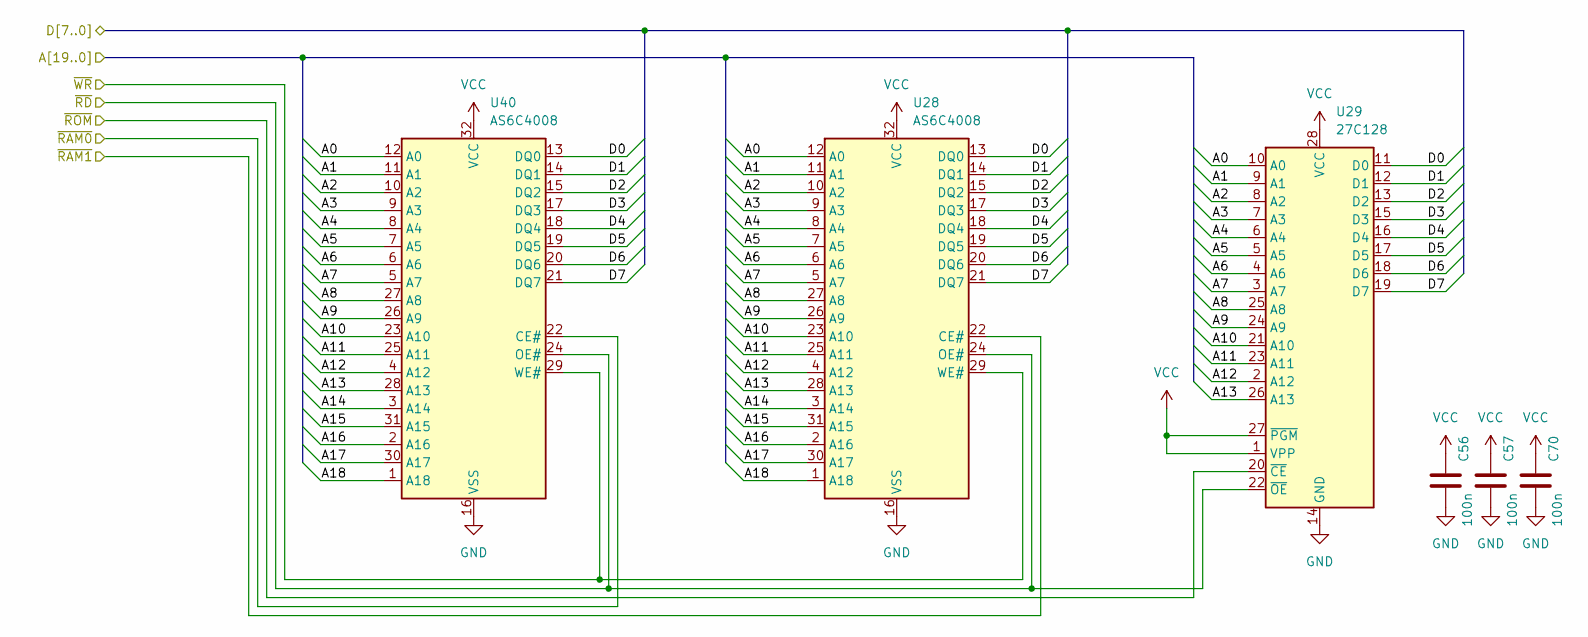
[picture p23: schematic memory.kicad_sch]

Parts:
C56, C57, C70: 100n; C_Disc_D5.0mm_W2.5mm_P2.50mm
U28, U40: AS6C4008; DIP-32_W15.24mm
U29: 27C128; DIP-28_W15.24mm

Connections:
/A0: U28.12 (A0), U29.10 (A0), U40.12 (A0); also elsewhere on the board
/A1: U28.11 (A1), U29.9 (A1), U40.11 (A1); also elsewhere on the board
/A2: U28.10 (A2), U29.8 (A2), U40.10 (A2); also elsewhere on the board
/A3: U28.9 (A3), U29.7 (A3), U40.9 (A3); also elsewhere on the board
/A4: U28.8 (A4), U29.6 (A4), U40.8 (A4); also elsewhere on the board
/A5: U28.7 (A5), U29.5 (A5), U40.7 (A5); also elsewhere on the board
/A6: U28.6 (A6), U29.4 (A6), U40.6 (A6); also elsewhere on the board
/A7: U28.5 (A7), U29.3 (A7), U40.5 (A7); also elsewhere on the board
/A8: U28.27 (A8), U29.25 (A8), U40.27 (A8); also elsewhere on the board
/A9: U28.26 (A9), U29.24 (A9), U40.26 (A9); also elsewhere on the board
/A10: U28.23 (A10), U29.21 (A10), U40.23 (A10); also elsewhere on the board
/A11: U28.25 (A11), U29.23 (A11), U40.25 (A11); also elsewhere on the board
/A12: U28.4 (A12), U29.2 (A12), U40.4 (A12); also elsewhere on the board
/A13: U28.28 (A13), U29.26 (A13), U40.28 (A13); also elsewhere on the board
/A14: U28.3 (A14), U40.3 (A14); also elsewhere on the board
/A15: U28.31 (A15), U40.31 (A15); also elsewhere on the board
/A16: U28.2 (A16), U40.2 (A16); also elsewhere on the board
/A17: U28.30 (A17), U40.30 (A17); also elsewhere on the board
/A18: U28.1 (A18), U40.1 (A18); also elsewhere on the board
/D0: U28.13 (DQ0), U29.11 (D0), U40.13 (DQ0); also elsewhere on the board
/D1: U28.14 (DQ1), U29.12 (D1), U40.14 (DQ1); also elsewhere on the board
/D2: U28.15 (DQ2), U29.13 (D2), U40.15 (DQ2); also elsewhere on the board
/D3: U28.17 (DQ3), U29.15 (D3), U40.17 (DQ3); also elsewhere on the board
/D4: U28.18 (DQ4), U29.16 (D4), U40.18 (DQ4); also elsewhere on the board
/D5: U28.19 (DQ5), U29.17 (D5), U40.19 (DQ5); also elsewhere on the board
/D6: U28.20 (DQ6), U29.18 (D6), U40.20 (DQ6); also elsewhere on the board
/D7: U28.21 (DQ7), U29.19 (D7), U40.21 (DQ7); also elsewhere on the board
/cf/~RD: U28.24 (OE#), U29.22 (~OE), U40.24 (OE#); also elsewhere on the board
/cf/~WR: U28.29 (WE#), U40.29 (WE#); also elsewhere on the board
/cpu/~RAM0: U40.22 (CE#); also elsewhere on the board
/cpu/~RAM1: U28.22 (CE#); also elsewhere on the board
/cpu/~ROM: U29.20 (~CE); also elsewhere on the board
GND: C56.2, C57.2, C70.2, U28.16 (VSS), U29.14 (GND), U40.16 (VSS); also elsewhere on the board
VCC: C56.1, C57.1, C70.1, U28.32 (VCC), U29.1 (VPP), U29.27 (~PGM), U29.28 (VCC), U40.32 (VCC); also elsewhere on the board

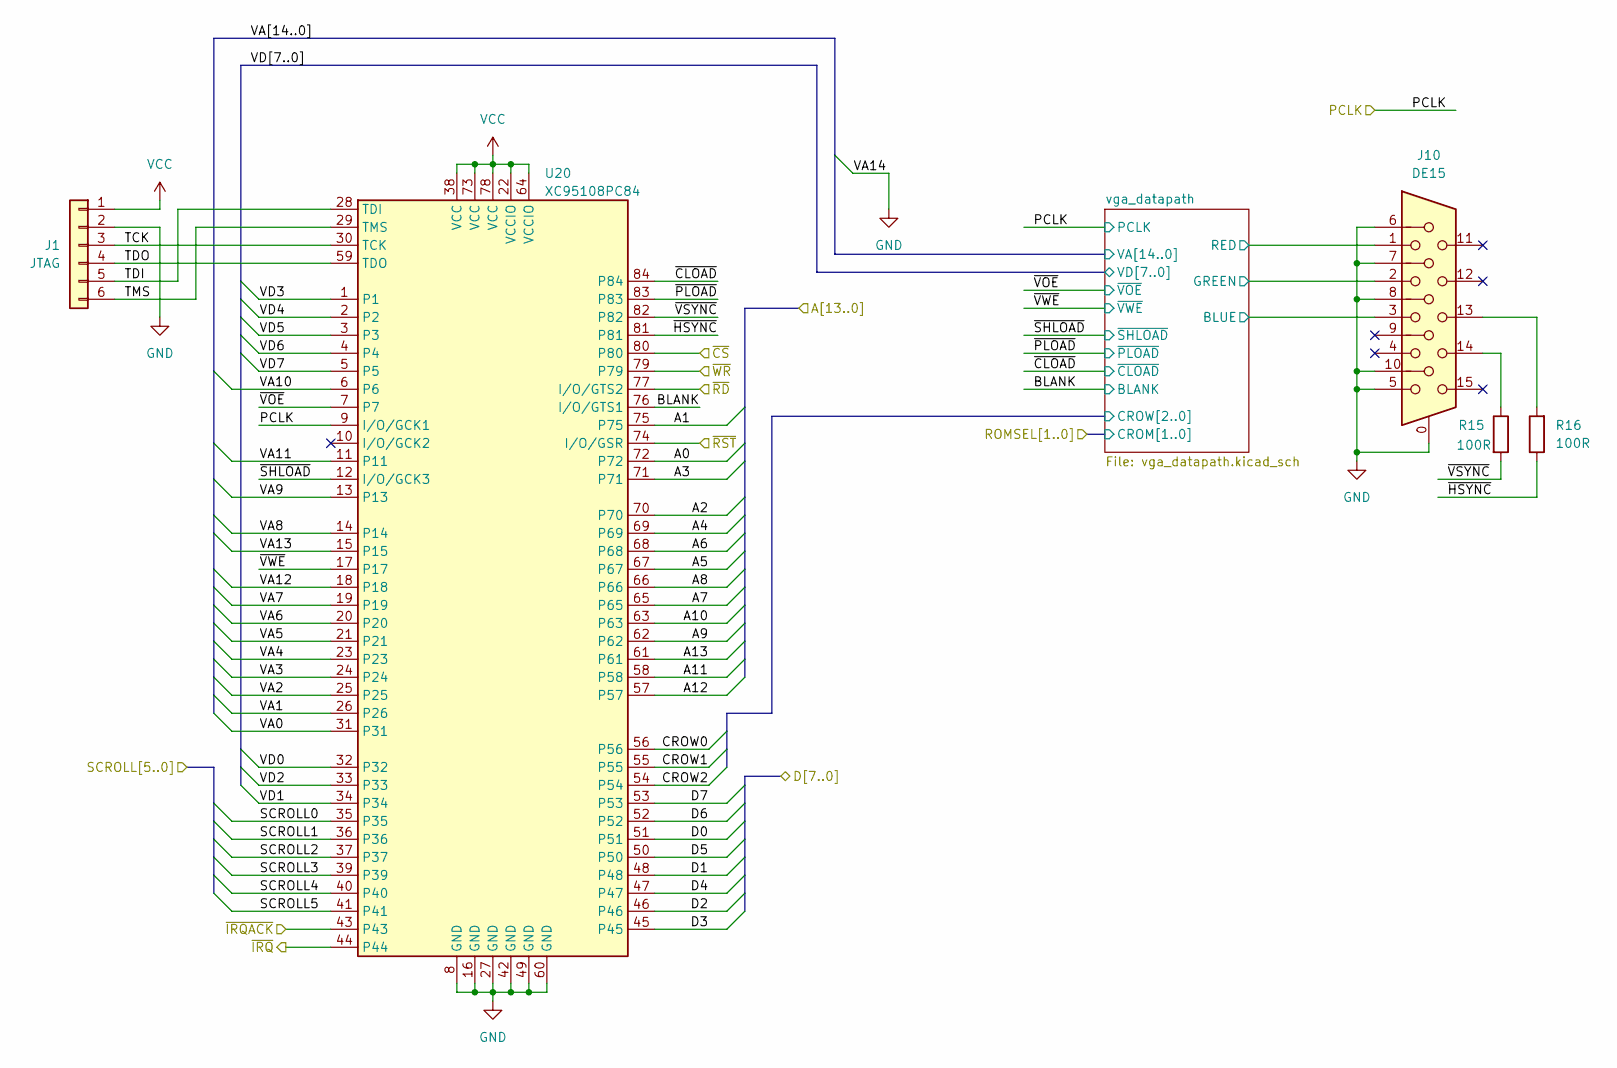
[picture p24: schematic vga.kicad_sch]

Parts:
J1: JTAG; PinHeader_1x06_P2.54mm_Vertical
J10: DE15; DSUB-15-HD_Socket_Horizontal_P2.29x1.90mm_EdgePinOffset3.03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
R15, R16: 100R; R_Axial_DIN0207_L6.3mm_D2.5mm_P7.62mm_Horizontal
U20: XC95108PC84; PLCC-84_THT-Socket

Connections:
/A0: U20.72; also elsewhere on the board
/A1: U20.75; also elsewhere on the board
/A2: U20.70; also elsewhere on the board
/A3: U20.71; also elsewhere on the board
/A4: U20.69; also elsewhere on the board
/A5: U20.67; also elsewhere on the board
/A6: U20.68; also elsewhere on the board
/A7: U20.65; also elsewhere on the board
/A8: U20.66; also elsewhere on the board
/A9: U20.62; also elsewhere on the board
/A10: U20.63; also elsewhere on the board
/A11: U20.58; also elsewhere on the board
/A12: U20.57; also elsewhere on the board
/A13: U20.61; also elsewhere on the board
/D0: U20.51; also elsewhere on the board
/D1: U20.48; also elsewhere on the board
/D2: U20.46; also elsewhere on the board
/D3: U20.45; also elsewhere on the board
/D4: U20.47; also elsewhere on the board
/D5: U20.50; also elsewhere on the board
/D6: U20.52; also elsewhere on the board
/D7: U20.53; also elsewhere on the board
/cf/~RD: U20.77 (I/O/GTS2); also elsewhere on the board
/cf/~WR: U20.79; also elsewhere on the board
/cpu/~RST: U20.74 (I/O/GSR); also elsewhere on the board
/cpu/~VBLANKACK: U20.43; also elsewhere on the board
/cpu/~VBLANK: U20.44; also elsewhere on the board
/cpu/~VRAM: U20.80; also elsewhere on the board
/sound/SCROLL0: U20.35; also elsewhere on the board
/sound/SCROLL1: U20.36; also elsewhere on the board
/sound/SCROLL2: U20.37; also elsewhere on the board
/sound/SCROLL3: U20.39; also elsewhere on the board
/sound/SCROLL4: U20.40; also elsewhere on the board
/sound/SCROLL5: U20.41; also elsewhere on the board
/vga/BLANK: U20.76 (I/O/GTS1); also elsewhere on the board
/vga/PCLK: U20.9 (I/O/GCK1); also elsewhere on the board
/vga/TCK: J1.3, U20.30 (TCK)
/vga/TDI: J1.5, U20.28 (TDI)
/vga/TDO: J1.4, U20.59 (TDO)
/vga/TMS: J1.6, U20.29 (TMS)
/vga/VA0: U20.31; also elsewhere on the board
/vga/VA1: U20.26; also elsewhere on the board
/vga/VA2: U20.25; also elsewhere on the board
/vga/VA3: U20.24; also elsewhere on the board
/vga/VA4: U20.23; also elsewhere on the board
/vga/VA5: U20.21; also elsewhere on the board
/vga/VA6: U20.20; also elsewhere on the board
/vga/VA7: U20.19; also elsewhere on the board
/vga/VA8: U20.14; also elsewhere on the board
/vga/VA9: U20.13; also elsewhere on the board
/vga/VA10: U20.6; also elsewhere on the board
/vga/VA11: U20.11; also elsewhere on the board
/vga/VA12: U20.18; also elsewhere on the board
/vga/VA13: U20.15; also elsewhere on the board
/vga/VD0: U20.32; also elsewhere on the board
/vga/VD1: U20.34; also elsewhere on the board
/vga/VD2: U20.33; also elsewhere on the board
/vga/VD3: U20.1; also elsewhere on the board
/vga/VD4: U20.2; also elsewhere on the board
/vga/VD5: U20.3; also elsewhere on the board
/vga/VD6: U20.4; also elsewhere on the board
/vga/VD7: U20.5; also elsewhere on the board
/vga/vga_datapath/BLUE: J10.3; also elsewhere on the board
/vga/vga_datapath/CROW0: U20.56; also elsewhere on the board
/vga/vga_datapath/CROW1: U20.55; also elsewhere on the board
/vga/vga_datapath/CROW2: U20.54; also elsewhere on the board
/vga/vga_datapath/GREEN: J10.2; also elsewhere on the board
/vga/vga_datapath/RED: J10.1; also elsewhere on the board
/vga/~CLOAD: U20.84; also elsewhere on the board
/vga/~HSYNC: R16.1, U20.81
/vga/~PLOAD: U20.83; also elsewhere on the board
/vga/~SHLOAD: U20.12 (I/O/GCK3); also elsewhere on the board
/vga/~VOE: U20.7; also elsewhere on the board
/vga/~VSYNC: R15.2, U20.82
/vga/~VWE: U20.17; also elsewhere on the board
GND: J1.2, J10.0, J10.5, J10.6, J10.7, J10.8, J10.10, U20.8 (GND), U20.16 (GND), U20.27 (GND), U20.42 (GND), U20.49 (GND), U20.60 (GND); also elsewhere on the board
unnamed: J10.13, R16.2
unnamed: J10.14, R15.1
VCC: J1.1, U20.22 (VCCIO), U20.38 (VCC), U20.64 (VCCIO), U20.73 (VCC), U20.78 (VCC); also elsewhere on the board

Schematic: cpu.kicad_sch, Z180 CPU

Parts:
C38, C39: 22p; C_Disc_D5.0mm_W2.5mm_P2.50mm
C40, C41, C42, C72: 100n; C_Disc_D5.0mm_W2.5mm_P2.50mm
IC1: Z180; PLCC-68_THT-Socket; Manufacturer_Part_Number Z8S18033VSG; Mouser Part Number 692-Z8S18033VSG
RN2: 47K; R_Array_SIP9
U8: 74HC138; DIP-16_W7.62mm
U31: ZAK181MD (GAL16V8); DIP-20_W7.62mm
Y2: 12.288 MHz; Crystal_HC49-4H_Vertical

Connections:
/A0: IC1.14 (A0); also elsewhere on the board
/A1: IC1.15 (A1); also elsewhere on the board
/A2: IC1.16 (A2); also elsewhere on the board
/A3: IC1.17 (A3); also elsewhere on the board
/A4: IC1.19 (A4); also elsewhere on the board
/A5: IC1.20 (A5), U8.3 (A2); also elsewhere on the board
/A6: IC1.21 (A6), U8.2 (A1); also elsewhere on the board
/A7: IC1.22 (A7), U8.1 (A0); also elsewhere on the board
/A8: IC1.23 (A8); also elsewhere on the board
/A9: IC1.24 (A9); also elsewhere on the board
/A10: IC1.25 (A10); also elsewhere on the board
/A11: IC1.26 (A11); also elsewhere on the board
/A12: IC1.27 (A12); also elsewhere on the board
/A13: IC1.28 (A13), U31.8 (I8); also elsewhere on the board
/A14: IC1.29 (A14), U31.7 (I7); also elsewhere on the board
/A15: IC1.30 (A15), U31.6 (I6); also elsewhere on the board
/A16: IC1.31 (A16), U31.5 (I5); also elsewhere on the board
/A17: IC1.32 (A17), U31.4 (I4); also elsewhere on the board
/A18: IC1.33 (A18/TOUT), U31.3 (I3); also elsewhere on the board
/A19: IC1.35 (A19), U31.2 (I2)
/D0: IC1.37 (D0), U31.11 (I10/~OE); also elsewhere on the board
/D1: IC1.38 (D1); also elsewhere on the board
/D2: IC1.39 (D2); also elsewhere on the board
/D3: IC1.40 (D3); also elsewhere on the board
/D4: IC1.41 (D4); also elsewhere on the board
/D5: IC1.42 (D5); also elsewhere on the board
/D6: IC1.43 (D6); also elsewhere on the board
/D7: IC1.44 (D7); also elsewhere on the board
/cf/~CS: U8.7 (~Y7); also elsewhere on the board
/cf/~RD: IC1.67 (~RD); also elsewhere on the board
/cf/~WR: IC1.66 (~WR); also elsewhere on the board
/cpu/CLK: IC1.68 (PHI); also elsewhere on the board
/cpu/RX0: IC1.49 (RXA0); also elsewhere on the board
/cpu/RX1: IC1.53 (RXA1); also elsewhere on the board
/cpu/TX0: IC1.48 (TXA0); also elsewhere on the board
/cpu/TX1: IC1.51 (TXA1); also elsewhere on the board
/cpu/~CTS0: IC1.46 (~CTS0); also elsewhere on the board
/cpu/~DREQ1: IC1.58 (~DREQ1), RN2.2 (R1)
/cpu/~HALT: IC1.60 (~HALT); also elsewhere on the board
/cpu/~INT0: IC1.10 (~INT0), RN2.8 (R7); also elsewhere on the board
/cpu/~INT1: IC1.11 (~INT1), RN2.7 (R6); also elsewhere on the board
/cpu/~IORQ: IC1.62 (~IORQ), U8.4 (~E0); also elsewhere on the board
/cpu/~KEYBOARD: U8.11 (~Y4); also elsewhere on the board
/cpu/~M1: IC1.65 (~M1), U8.6 (E2); also elsewhere on the board
/cpu/~MREQ: IC1.63 (~MREQ), U31.9 (I9)
/cpu/~NMI: IC1.9 (~NMI), RN2.9 (R8)
/cpu/~PIO: U8.10 (~Y5); also elsewhere on the board
/cpu/~RAM0: U31.12 (IO8); also elsewhere on the board
/cpu/~RAM1: U31.19 (IO1); also elsewhere on the board
/cpu/~ROMDIS: U8.12 (~Y3), U31.14 (IO6)
/cpu/~ROM: U31.13 (IO7); also elsewhere on the board
/cpu/~RST: IC1.8 (~RESET), U31.16 (IO4); also elsewhere on the board
/cpu/~RTS0: IC1.45 (~RTS0); also elsewhere on the board
/cpu/~SOUND: U8.9 (~Y6); also elsewhere on the board
/cpu/~VBLANKACK: U8.13 (~Y2); also elsewhere on the board
/cpu/~VBLANK: IC1.12 (~INT2), RN2.6 (R5); also elsewhere on the board
/cpu/~VRAM: U31.18 (IO2); also elsewhere on the board
/cpu/~WAIT: IC1.5 (~WAIT), RN2.5 (R4)
GND: C38.1, C39.1, C40.2, C41.2, C42.2, C72.2, IC1.1 (VSS_1), IC1.2 (VSS_2), IC1.18 (VSS_3), IC1.36 (VSS_4), U8.5 (~E1), U8.8 (GND), U31.1 (I1/CLK), U31.10 (GND); also elsewhere on the board
unnamed: IC1.50 (CKA0/~DREQ0), RN2.3 (R2)
unnamed: C39.2, IC1.4 (EXTAL), Y2.2
unnamed: C38.2, IC1.3 (XTAL), Y2.1
unnamed: IC1.7 (~BUSREQ), RN2.4 (R3)
VCC: C40.1, C41.1, C42.1, C72.1, IC1.34 (VDD), RN2.1 (common), U8.16 (VCC), U31.20 (VCC); also elsewhere on the board

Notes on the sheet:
Z180 internal I/O (0x00:0x3F)
GAL16V8 ZAK181MD NC A19 A18 A17 A16 A15 A14 A13 /MREQ GND DAT /RAM0 /ROM /ROMCTRL NC /RST ROMDIS /VRAM /RAM1 VCC VRAM = A14 * A15 * A16 * A17 * A18 * A19 * MREQ ROM = /A14 * /A15 * /A16 * /A17 * /A18 * /A19 * MREQ * /ROMDIS RAM0 = /VRAM * /ROM * MREQ * /A19 RAM1 = /VRAM * /ROM * MREQ * A19 ROMDIS =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

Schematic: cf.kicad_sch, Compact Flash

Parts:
C73: 100p; C_Disc_D5.0mm_W2.5mm_P2.50mm
D3: ACTIVITY; LED_D5.0mm
J3: Compact Flash; Conn_CF_N7E50-Q516XX-40
R19: 1K; R_Axial_DIN0207_L6.3mm_D2.5mm_P7.62mm_Horizontal
R20: 100R; R_Axial_DIN0207_L6.3mm_D2.5mm_P7.62mm_Horizontal
RN3: 1K; R_Array_SIP5

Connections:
/A0: J3.20 (A0); also elsewhere on the board
/A1: J3.19 (A1); also elsewhere on the board
/A2: J3.18 (A2); also elsewhere on the board
/D0: J3.21 (D0); also elsewhere on the board
/D1: J3.22 (D1); also elsewhere on the board
/D2: J3.23 (D2); also elsewhere on the board
/D3: J3.2 (D3); also elsewhere on the board
/D4: J3.3 (D4); also elsewhere on the board
/D5: J3.4 (D5); also elsewhere on the board
/D6: J3.5 (D6); also elsewhere on the board
/D7: J3.6 (D7); also elsewhere on the board
/cf/IRQ: J3.37 (INTRQ); also elsewhere on the board
/cf/~CS: J3.7 (~CS0); also elsewhere on the board
/cf/~RD: R20.2; also elsewhere on the board
/cf/~WR: J3.35 (~IOWR); also elsewhere on the board
/cpu/~RST: J3.41 (~RESET); also elsewhere on the board
GND: C73.2, J3.1 (GND), J3.8 (A10), J3.9 (~ATASEL), J3.10 (A9), J3.11 (A8), J3.12 (A7), J3.14 (A6), J3.15 (A5), J3.16 (A4), J3.17 (A3), J3.39 (~CSEL), J3.50 (GND); also elsewhere on the board
unnamed: D3.2 (A), R19.1
unnamed: D3.1 (K), J3.45 (~DASP)
unnamed: J3.32 (~CS1), RN3.5 (R4)
unnamed: C73.1, J3.34 (~IORD), R20.1
unnamed: J3.46 (~PDIAG), RN3.2 (R1)
unnamed: J3.44 (~REG), RN3.4 (R3)
unnamed: J3.36 (~WE), RN3.3 (R2)
VCC: J3.13 (VCC), J3.38 (VCC), R19.2, RN3.1 (common); also elsewhere on the board

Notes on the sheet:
Regarding CF slot footprint: Market is a proper mess. These cards seem to be obsolete and everything is hard to aquire. Footprint used fits somewhat avaiable CF-50P - normal order, not reversed! Card has to be label up when inserted!

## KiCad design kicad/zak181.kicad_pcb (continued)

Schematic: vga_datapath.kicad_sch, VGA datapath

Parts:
C4, C5, C6, C7, C8, C9, C10, C11, C12, C13: 100n; C_Disc_D5.0mm_W2.5mm_P2.50mm
Q3, Q4, Q5: BC547; TO-92
R6, R11, R14: 390R; R_Axial_DIN0207_L6.3mm_D2.5mm_P7.62mm_Horizontal
R7, R8, R9, R10, R12, R13: 3K3; R_Axial_DIN0207_L6.3mm_D2.5mm_P7.62mm_Horizontal
U21, U30: 74HC377; DIP-20_W7.62mm
U23: 27C64; DIP-28_W15.24mm
U24: 74HC166; DIP-16_W7.62mm
U27: 62256; DIP-28_W15.24mm
U32: 74HC157; DIP-16_W7.62mm

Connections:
/sound/ROMSEL0: U23.23 (A11); also elsewhere on the board
/sound/ROMSEL1: U23.2 (A12); also elsewhere on the board
/vga/BLANK: U32.15 (E); also elsewhere on the board
/vga/PCLK: U21.11 (CP), U24.7 (Clk), U30.11 (CP); also elsewhere on the board
/vga/VA0: U27.10 (A0); also elsewhere on the board
/vga/VA1: U27.9 (A1); also elsewhere on the board
/vga/VA2: U27.8 (A2); also elsewhere on the board
/vga/VA3: U27.7 (A3); also elsewhere on the board
/vga/VA4: U27.6 (A4); also elsewhere on the board
/vga/VA5: U27.5 (A5); also elsewhere on the board
/vga/VA6: U27.4 (A6); also elsewhere on the board
/vga/VA7: U27.3 (A7); also elsewhere on the board
/vga/VA8: U27.25 (A8); also elsewhere on the board
/vga/VA9: U27.24 (A9); also elsewhere on the board
/vga/VA10: U27.21 (A10); also elsewhere on the board
/vga/VA11: U27.23 (A11); also elsewhere on the board
/vga/VA12: U27.2 (A12); also elsewhere on the board
/vga/VA13: U27.26 (A13); also elsewhere on the board
/vga/VD0: U21.3 (D0), U27.11 (Q0), U30.3 (D0); also elsewhere on the board
/vga/VD1: U21.4 (D1), U27.12 (Q1), U30.4 (D1); also elsewhere on the board
/vga/VD2: U21.7 (D2), U27.13 (Q2), U30.7 (D2); also elsewhere on the board
/vga/VD3: U21.8 (D3), U27.15 (Q3), U30.8 (D3); also elsewhere on the board
/vga/VD4: U21.13 (D4), U27.16 (Q4), U30.13 (D4); also elsewhere on the board
/vga/VD5: U21.14 (D5), U27.17 (Q5), U30.14 (D5); also elsewhere on the board
/vga/VD6: U21.17 (D6), U27.18 (Q6), U30.17 (D6); also elsewhere on the board
/vga/VD7: U21.18 (D7), U27.19 (Q7), U30.18 (D7); also elsewhere on the board
/vga/vga_datapath/BLUE: R14.2; also elsewhere on the board
/vga/vga_datapath/CROW0: U23.10 (A0); also elsewhere on the board
/vga/vga_datapath/CROW1: U23.9 (A1); also elsewhere on the board
/vga/vga_datapath/CROW2: U23.8 (A2); also elsewhere on the board
/vga/vga_datapath/GREEN: R11.2; also elsewhere on the board
/vga/vga_datapath/RED: R6.2; also elsewhere on the board
/vga/~CLOAD: U30.1 (~E); also elsewhere on the board
/vga/~PLOAD: U21.1 (~E); also elsewhere on the board
/vga/~SHLOAD: U24.15 (PE); also elsewhere on the board
/vga/~VOE: U27.22 (~OE); also elsewhere on the board
/vga/~VWE: U27.27 (~WE); also elsewhere on the board
GND: C4.2, C5.2, C6.2, C7.2, C8.2, C9.2, C10.2, C11.2, C12.2, C13.2, U21.10 (GND), U23.14 (GND), U23.20 (~CE), U23.22 (~OE), U24.1 (Ds), U24.6 (CE), U24.8 (GND), U27.1 (A14), U27.14 (GND), U27.20 (~CS), U30.10 (GND), U32.8 (GND); also elsewhere on the board
unnamed: Q3.2 (B), R7.2, R8.2
unnamed: Q3.3 (E), R6.1
unnamed: Q4.2 (B), R9.2, R10.2
unnamed: Q4.3 (E), R11.1
unnamed: Q5.2 (B), R12.2, R13.2
unnamed: Q5.3 (E), R14.1
unnamed: U21.2 (Q0), U23.7 (A3)
unnamed: U21.5 (Q1), U23.6 (A4)
unnamed: U21.6 (Q2), U23.5 (A5)
unnamed: U21.9 (Q3), U23.4 (A6)
unnamed: U21.12 (Q4), U23.3 (A7)
unnamed: U21.15 (Q5), U23.25 (A8)
unnamed: U21.16 (Q6), U23.24 (A9)
unnamed: U21.19 (Q7), U23.21 (A10)
unnamed: U23.11 (D0), U24.2 (A)
unnamed: U23.12 (D1), U24.3 (B)
unnamed: U23.13 (D2), U24.4 (C)
unnamed: U23.15 (D3), U24.5 (D)
unnamed: U23.16 (D4), U24.10 (E)
unnamed: U23.17 (D5), U24.11 (F)
unnamed: U23.18 (D6), U24.12 (G)
unnamed: U23.19 (D7), U24.14 (H)
unnamed: U24.13 (Qh), U32.1 (S)
unnamed: U30.2 (Q0), U32.2 (I0a)
unnamed: U30.5 (Q1), U32.5 (I0b)
unnamed: U30.6 (Q2), U32.11 (I0c)
unnamed: U30.9 (Q3), U32.14 (I0d)
unnamed: U30.12 (Q4), U32.3 (I1a)
unnamed: U30.15 (Q5), U32.6 (I1b)
unnamed: U30.16 (Q6), U32.10 (I1c)
unnamed: U30.19 (Q7), U32.13 (I1d)
unnamed: R7.1, U32.4 (Za)
unnamed: R9.1, U32.7 (Zb)
unnamed: R12.1, U32.9 (Zc)
unnamed: R8.1, R10.1, R13.1, U32.12 (Zd)
VCC: C4.1, C5.1, C6.1, C7.1, C8.1, C9.1, C10.1, C11.1, C12.1, C13.1, Q3.1 (C), Q4.1 (C), Q5.1 (C), U21.20 (VCC), U23.1 (VPP), U23.27 (~PGM), U23.28 (VCC), U24.9 (Clr), U24.16 (VCC), U27.28 (VCC), U30.20 (VCC), U32.16 (VCC); also elsewhere on the board

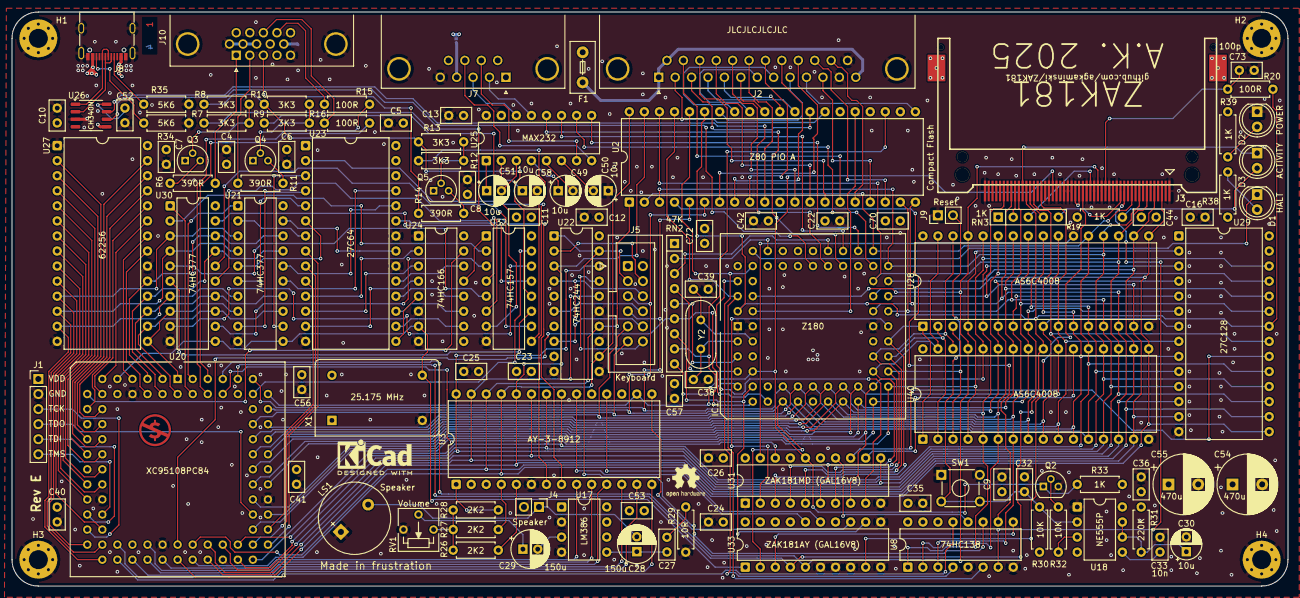
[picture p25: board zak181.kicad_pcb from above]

Board: 4 copper layers, 215.3 x 96.8 mm, 118 parts (1 on the bottom side), 219 nets.

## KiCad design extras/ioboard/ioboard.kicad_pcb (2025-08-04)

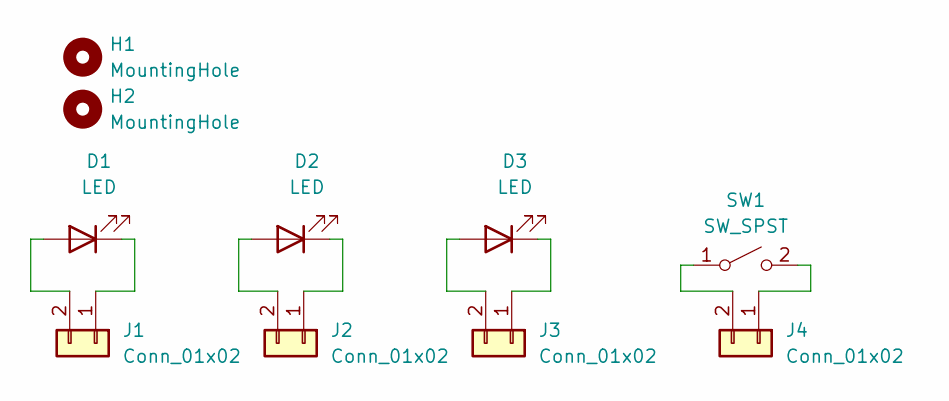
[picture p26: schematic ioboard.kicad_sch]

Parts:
D1, D2, D3: LED; LED_D5.0mm
H1, H2: MountingHole; MountingHole_3.2mm_M3_Pad_Via
J1, J2, J3, J4: Conn_01x02; PinHeader_1x02_P2.54mm_Vertical
SW1: SW_SPST; SW_PUSH_6mm

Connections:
unnamed: D1.2 (A), J1.2
unnamed: D1.1 (K), J1.1
unnamed: D2.2 (A), J2.2
unnamed: D2.1 (K), J2.1
unnamed: D3.2 (A), J3.2
unnamed: D3.1 (K), J3.1
unnamed: J4.1, SW1.2 (B)
unnamed: J4.2, SW1.1 (A)

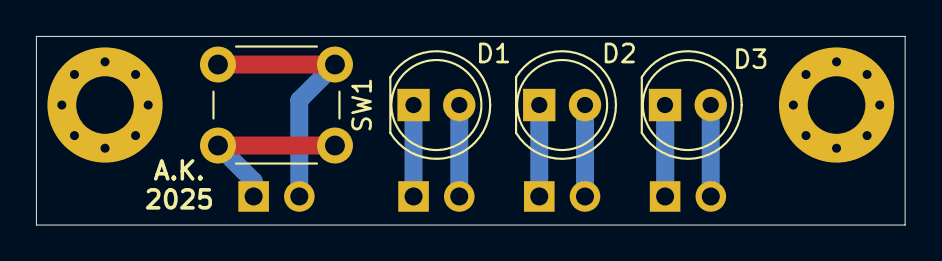
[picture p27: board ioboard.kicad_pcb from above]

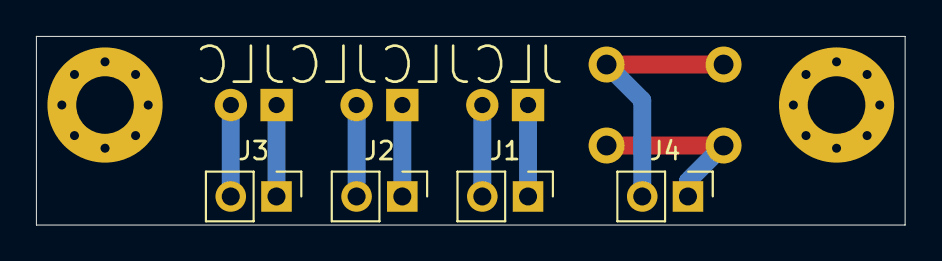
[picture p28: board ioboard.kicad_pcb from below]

Board: 2 copper layers, 48.3 x 10.5 mm, 10 parts (4 on the bottom side), 8 nets.

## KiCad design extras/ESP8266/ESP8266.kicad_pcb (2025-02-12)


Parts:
C1, C2, C3: 10u; C_0805_2012Metric_Pad1.18x1.45mm_HandSolder
C4, C7: 22u; CP_EIA-3528-15_AVX-H_Pad1.50x2.35mm_HandSolder
C5, C6: 100n; C_0805_2012Metric_Pad1.18x1.45mm_HandSolder
D1, D2: 1N4148; D_MiniMELF
J1: DE9_Receptacle; DSUB-9_Female_EdgeMount_P2.77mm
JP1: ~{CTS}; SolderJumper-2_P1.3mm_Bridged_RoundedPad1.0x1.5mm
JP2: ~{RTS}; SolderJumper-2_P1.3mm_Bridged_RoundedPad1.0x1.5mm
R1: 2K2; R_0805_2012Metric_Pad1.15x1.40mm_HandSolder
R2: 3K3; R_0805_2012Metric_Pad1.15x1.40mm_HandSolder
SW1: BOOT; SW_SPST_PTS645
U1: ESP32-WROOM-32E; ESP32-WROOM-32D
U2: MAX3232; SOP-16_4.4x10.4mm_P1.27mm
U3: AMS1117; SOT-223-3_TabPin2

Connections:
/RS232_RX: J1.2, U2.7 (T2OUT)
/RS232_TX: J1.3, U2.13 (R1IN)
/~RS232_CTS: D1.2 (A), J1.8, U2.14 (T1OUT)
/~RS232_RTS: J1.7, U2.8 (R2IN)
GND: C4.2, C5.2, C6.2, C7.2, J1.5, R2.2, SW1.2, U1.1 (GND), U1.15 (GND), U1.38 (GND), U1.39 (GND), U2.15 (GND)
unnamed: C6.1, C7.1, D1.1 (K), D2.1 (K), U3.3 (VI)
unnamed: D2.2 (A), J1.4
unnamed: JP1.1 (A), U1.31 (IO19)
unnamed: JP1.2 (B), U2.9 (R2OUT)
unnamed: JP2.1 (A), U1.36 (IO22)
unnamed: JP2.2 (B), U2.11 (T1IN)
unnamed: SW1.1, U1.25 (IO0)
unnamed: U1.34 (RXD0/IO3), U2.12 (R1OUT)
unnamed: U1.35 (TXD0/IO1), U2.10 (T2IN)
unnamed: C3.2, U2.1 (C1+)
unnamed: C3.1, U2.3 (C1-)
unnamed: C2.1, U2.4 (C2+)
unnamed: C2.2, U2.5 (C2-)
unnamed: C1.1, U2.2 (VS+)
unnamed: C1.2, U2.6 (VS-)
unnamed: R1.2, R2.1, U3.1 (ADJ)
VCC: C4.1, C5.1, R1.1, U1.2 (VDD), U1.3 (EN), U2.16 (VCC), U3.2 (VO)

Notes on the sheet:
Vout = 3V3



Board: 2 copper layers, 20.3 x 25.7 mm, 18 parts (14 on the bottom side), 22 nets.

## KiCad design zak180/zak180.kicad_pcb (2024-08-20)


Board: 2 copper layers, 163 parts (0 on the bottom side), 250 nets, no tracks yet.

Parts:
C1: 4u7; C_Disc_D4.3mm_W1.9mm_P5.00mm
C2, C3, C38, C39: 22p; C_Disc_D4.3mm_W1.9mm_P5.00mm
C4, C5, C6, C7, C8, C9, C10, C11, C12, C13, C14, C15, C16, C17, C18, C19, C20, C21, C22, C23, C24, C25, C26, C32, C35, C36, C37, C40, C41, C42, C43, C44, C45, C46, C47, C48, C52, C53, C56, C57, C58, C59, C60, C61, C62, C63, C64, C65, C66, C67, C68, C69, C70, C71, C72: 100n; C_Disc_D5.0mm_W2.5mm_P2.50mm
C27: 47n; C_Disc_D5.0mm_W2.5mm_P2.50mm
C28, C30, C31: 150u; CP_Radial_D10.0mm_P5.00mm
C29: 22u; CP_Radial_D10.0mm_P5.00mm
C33: 10n; C_Disc_D5.0mm_W2.5mm_P2.50mm
C34: 1u; C_Disc_D5.0mm_W2.5mm_P2.50mm
C49, C50, C51: 10u; CP_Radial_D5.0mm_P2.50mm
C54, C55: 470u; CP_Radial_D10.0mm_P5.00mm
D1: HALT; LED_D5.0mm
D2: POWER; LED_D5.0mm
F1: Fuse; Fuse_Littelfuse_395Series
IC1: Z8-L180-S180-180-PLCC-68; PLCC-68_THT-Socket
J1: Conn_02x17_Odd_Even; IDC-Header_2x17_P2.54mm_Vertical
J2: DB25_Receptacle_MountingHoles; DSUB-25_Female_Horizontal_P2.77x2.84mm_EdgePinOffset9.90mm_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
J3: DE15_Receptacle_HighDensity_MountingHoles; DSUB-15-HD_Female_Horizontal_P2.29x1.98mm_EdgePinOffset3.03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
J4: Speaker; PinHeader_1x02_P1.00mm_Vertical
J5: Conn_02x06_Odd_Even; IDC-Header_2x06_P2.54mm_Vertical
J6: Floppy Power; PinHeader_1x04_P2.54mm_Horizontal
J7: DE9_Plug_MountingHoles; DSUB-9_Male_Horizontal_P2.77x2.84mm_EdgePinOffset7.70mm_Hou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
J8: USB_C_Receptacle_USB2.0_14P; USB_C_Receptacle_G-Switch_GT-USB-7010ASV
JTAG1: Conn_02x05_Odd_Even; IDC-Header_2x05_P2.54mm_Vertical
Q1, Q2: BC547; TO-92
R1, R2, R6, R7, R8, R9, R10, R11, R12, R13, R14, R15, R16, R17, R18, R19, R20, R21, R22, R23, R24, R25: 100R; R_Axial_DIN0207_L6.3mm_D2.5mm_P7.62mm_Horizontal
R3, R4, R5: 470R; R_Axial_DIN0207_L6.3mm_D2.5mm_P7.62mm_Horizontal
R26, R27, R28: 2K2; R_Axial_DIN0207_L6.3mm_D2.5mm_P7.62mm_Horizontal
R29: 10R; R_Axial_DIN0207_L6.3mm_D2.5mm_P7.62mm_Horizontal
R30, R32: 10K; R_Axial_DIN0207_L6.3mm_D2.5mm_P7.62mm_Horizontal
R31: 220K; R_Axial_DIN0207_L6.3mm_D2.5mm_P7.62mm_Horizontal
R33, R38, R39: 1K; R_Axial_DIN0207_L6.3mm_D2.5mm_P7.62mm_Horizontal
R34, R35: 1K5; R_Axial_DIN0207_L6.3mm_D2.5mm_P7.62mm_Horizontal
R36, R37: 47K; R_Axial_DIN0207_L6.3mm_D2.5mm_P7.62mm_Horizontal
RN1: 1K; R_Array_SIP9
RN2: 47K; R_Array_SIP9
RV1: 1K; Potentiometer_Vishay_T73YP_Vertical
SW1: Reset; SW_TH_Tactile_Omron_B3F-10xx
U1: 82077AA/PC8477; PLCC-68_THT-Socket
U2: PIO-DIP-40; DIP-40_W15.24mm
U3: PSG_AY-3-8912; DIP-28_W15.24mm
U4, U6, U22: 74HC244; DIP-20_W7.62mm
U5: XC9536PC44; PLCC-44_THT-Socket
U7, U11: 74HC02; DIP-14_W7.62mm
U8: 74HC138; DIP-16_W7.62mm
U9: 74HC245; DIP-20_W7.62mm
U10: 6264; DIP-28_W15.24mm
U12: 74HC574; DIP-20_W7.62mm
U13: 74HC174; DIP-16_W7.62mm
U14: 2764; DIP-28_W15.24mm
U15: 74HC166; DIP-16_W7.62mm
U16, U30: 74HC00; DIP-14_W7.62mm
U17: LM386; DIP-8_W7.62mm
U18: NE555P; DIP-8_W7.62mm
U19: 74HC163; DIP-16_W7.62mm
U20, U21: 74HC688; DIP-20_W7.62mm
U23: 74HC74; DIP-14_W7.62mm
U25: MAX232; DIP-16_W7.62mm
U26: CH340N; SOP-8_3.9x4.9mm_P1.27mm
U27: 74HC32; DIP-14_W7.62mm
U28, U40: AS6C4008-55PCN; DIP-32_W15.24mm
U29: 27C128; DIP-28_W15.24mm
X1: 25.175 MHz; Oscillator_DIP-14
Y1: 24 MHz; Crystal_HC49-4H_Vertical
Y2: 16 MHz; Crystal_HC49-4H_Vertical

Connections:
/clock/1.57 MHz: U3.15 (CLOCK), U19.11 (Q3)
/clock/25.175 MHz: U5.5 (I/O/GCK1), U12.11 (Cp), U13.9 (Cp), U15.7 (Clk), U19.2 (CP), X1.8 (OUT)
/clock/RST: Q2.2 (B), R32.2, U1.32 (RESET)
/clock/~RST: IC1.8 (~RESET), Q2.1 (C), R33.1, U3.16 (~RESET), U5.39 (I/O/GSR), U23.1 (~R)
/cpu/A0: IC1.14 (A0), U1.7 (A0), U2.19 (D0), U4.2 (1A0), U22.18 (1Y0), U28.12 (A0), U29.10 (A0), U40.12 (A0)
/cpu/A1: IC1.15 (A1), U1.8 (A1), U2.20 (D1), U4.4 (1A1), U22.16 (1Y1), U28.11 (A1), U29.9 (A1), U40.11 (A1)
/cpu/A2: IC1.16 (A2), U1.10 (A2), U2.1 (D2), U4.6 (1A2), U22.14 (1Y2), U28.10 (A2), U29.8 (A2), U40.10 (A2)
/cpu/A3: IC1.17 (A3), U2.40 (D3), U4.8 (1A3), U22.12 (1Y3), U28.9 (A3), U29.7 (A3), U40.9 (A3)
/cpu/A4: IC1.19 (A4), U2.39 (D4), U4.17 (2A0), U22.3 (2Y0), U28.8 (A4), U29.6 (A4), U40.8 (A4)
/cpu/A5: IC1.20 (A5), U2.38 (D5), U4.15 (2A1), U8.3 (A2), U28.7 (A5), U29.5 (A5), U40.7 (A5)
/cpu/A6: IC1.21 (A6), U2.3 (D6), U4.13 (2A2), U8.2 (A1), U28.6 (A6), U29.4 (A6), U40.6 (A6)
/cpu/A7: IC1.22 (A7), U2.2 (D7), U6.2 (1A0), U8.1 (A0), U28.5 (A7), U29.3 (A7), U40.5 (A7)
/cpu/A8: IC1.23 (A8), U6.4 (1A1), U28.27 (A8), U29.25 (A8), U40.27 (A8)
/cpu/A9: IC1.24 (A9), U6.6 (1A2), U28.26 (A9), U29.24 (A9), U40.26 (A9)
/cpu/A10: IC1.25 (A10), U6.8 (1A3), U28.23 (A10), U29.21 (A10), U40.23 (A10)
/cpu/A11: IC1.26 (A11), U6.17 (2A0), U28.25 (A11), U29.23 (A11), U40.25 (A11)
/cpu/A12: IC1.27 (A12), U6.15 (2A1), U28.4 (A12), U29.2 (A12), U40.4 (A12)
/cpu/A13: IC1.28 (A13), U21.4 (P1), U28.28 (A13), U29.26 (A13), U40.28 (A13)
/cpu/A14: IC1.29 (A14), U20.6 (P2), U21.6 (P2), U28.3 (A14), U40.3 (A14)
/cpu/A15: IC1.30 (A15), U20.8 (P3), U21.8 (P3), U28.31 (A15), U40.31 (A15)
/cpu/A16: IC1.31 (A16), U20.11 (P4), U21.11 (P4), U28.2 (A16), U40.2 (A16)
/cpu/A17: IC1.32 (A17), U20.13 (P5), U21.13 (P5), U28.30 (A17), U40.30 (A17)
/cpu/A18: IC1.33 (A18/TOUT), U20.15 (P6), U21.15 (P6), U28.1 (A18), U40.1 (A18)
/cpu/A19: IC1.35 (A19), U20.17 (P7), U21.17 (P7), U30.1, U30.2, U30.10
/cpu/CLK: IC1.68 (PHI), U2.25 (CLK)
/cpu/D0: IC1.37 (D0), J5.5, U1.11 (DB0), U2.6 (B/~A), U3.28 (D0), U9.2 (A0), U11.6, U23.2 (D), U28.13 (DQ0), U29.11 (D0), U40.13 (DQ0)
/cpu/D1: IC1.38 (D1), J5.7, U1.13 (DB1), U2.5 (C/~D), U3.27 (D1), U9.3 (A1), U28.14 (DQ1), U29.12 (D1), U40.14 (DQ1)
/cpu/D2: IC1.39 (D2), J5.9, U1.14 (DB2), U3.26 (D2), U9.4 (A2), U28.15 (DQ2), U29.13 (D2), U40.15 (DQ2)
/cpu/D3: IC1.40 (D3), J5.11, U1.15 (DB3), U3.25 (D3), U9.5 (A3), U28.17 (DQ3), U29.15 (D3), U40.17 (DQ3)
/cpu/D4: IC1.41 (D4), U1.17 (DB4), U3.24 (D4), U9.6 (A4), U28.18 (DQ4), U29.16 (D4), U40.18 (DQ4)
/cpu/D5: IC1.42 (D5), U1.19 (DB5), U3.23 (D5), U9.7 (A5), U28.19 (DQ5), U29.17 (D5), U40.19 (DQ5)
/cpu/D6: IC1.43 (D6), U1.20 (DB6), U3.22 (D6), U9.8 (A6), U28.20 (DQ6), U29.18 (D6), U40.20 (DQ6)
/cpu/D7: IC1.44 (D7), U1.22 (DB7), U3.21 (D7), U9.9 (A7), U28.21 (DQ7), U29.19 (D7), U40.21 (DQ7)
/cpu/RX0: IC1.49 (RXA0), U25.12 (R1OUT)
/cpu/RX1: IC1.53 (RXA1), U26.7 (RXD)
/cpu/TX0: IC1.48 (TXA0), U25.11 (T1IN)
/cpu/TX1: IC1.51 (TXA1), U26.6 (TXD)
/cpu/VBLANK: U5.19 (M14), U23.11 (C)
/cpu//ROMDIS: U8.12 (~Y3), U23.3 (C)
/cpu/~CTS0: IC1.46 (~CTS0), U25.9 (R2OUT)
/cpu/~FLOPPY: U1.6 (CS), U8.7 (~Y7)
/cpu/~HALT: D1.1 (K), IC1.60 (~HALT)
/cpu/~INT0: IC1.10 (~INT0), RN2.8 (R7), U2.23 (~INT)
/cpu/~INT1: IC1.11 (~INT1), RN2.7 (R6), U16.11
/cpu/~IORQ: IC1.62 (~IORQ), U2.36 (~IORQ), U8.4 (~E0)
/cpu/~KEYBOARD: J5.3, U8.11 (~Y4), U22.1 (1OE), U22.19 (2OE)
/cpu/~M1: IC1.65 (~M1), U2.37 (~M1), U8.6 (E2)
/cpu/~NMI: IC1.9 (~NMI), RN2.9 (R8)
/cpu/~PIO: U2.4 (~CE), U8.10 (~Y5)
/cpu/~RAM: U27.6, U30.12, U30.13
/cpu/~RD: IC1.67 (~RD), U1.4 (~RD), U2.35 (~RD), U9.1 (A->B), U16.2, U28.24 (OE#), U29.22 (~OE), U40.24 (OE#)
/cpu/~ROM: U16.9, U27.3, U29.20 (~CE)
/cpu/~RTS0: IC1.45 (~RTS0), U25.10 (T2IN)
/cpu/~SOUND: U8.9 (~Y6), U11.3, U11.5
/cpu/~VBLANKACK: U8.13 (~Y2), U23.10 (~S)
/cpu/~VRAM: U4.1 (1OE), U4.19 (2OE), U6.1 (1OE), U6.19 (2OE), U7.2, U7.11, U7.12, U9.19 (CE), U16.10, U21.19 (P=R)
/cpu/~WAIT: IC1.5 (~WAIT), RN2.5 (R4)
/cpu/~WR: IC1.66 (~WR), U1.5 (~WR), U7.3, U11.2, U16.1, U28.29 (WE#), U40.29 (WE#)
/floppy/IRQ: U1.23 (INT), U16.12, U16.13
/floppy/TC: R37.1, U1.25 (TC)
/floppy/~DACK: R36.2, U1.3 (~DACK)
/sound/ROMSEL0: U3.8 (IOA6), U14.23 (A11)
/sound/ROMSEL1: U3.7 (IOA7), U14.2 (A12)
/sound/SCRL0: U3.14 (IOA0), U5.20 (M15)
/sound/SCRL1: U3.13 (IOA1), U5.22 (M16)
/sound/SCRL2: U3.12 (IOA2), U5.43 (M4)
/sound/SCRL3: U3.11 (IOA3), U5.44 (M2)
/sound/SCRL4: U3.10 (IOA4), U5.24 (M17)
/sound/SCRL5: U3.9 (IOA5), U5.38 (M7)
/vga/BLANK: U7.8, U13.2 (Q0)
/vga/COL3: U4.18 (1Y0), U5.18 (M13), U10.10 (A0)
/vga/COL4: U4.16 (1Y1), U5.14 (M12), U10.9 (A1)
/vga/COL5: U4.14 (1Y2), U5.13 (M11), U10.8 (A2)
/vga/COL6: U4.12 (1Y3), U5.12 (M10), U10.7 (A3)
/vga/COL7: U4.3 (2Y0), U5.11 (M9), U10.6 (A4)
/vga/COL8: U4.5 (2Y1), U5.9 (M8), U10.5 (A5)
/vga/COL9: U4.7 (2Y2), U5.8 (M6), U10.4 (A6)
/vga/GD0: U9.18 (B0), U10.11 (D0), U12.9 (D7)
/vga/GD1: U9.17 (B1), U10.12 (D1), U12.8 (D6)
/vga/GD2: U9.16 (B2), U10.13 (D2), U12.7 (D5)
/vga/GD3: U9.15 (B3), U10.15 (D3), U12.6 (D4)
/vga/GD4: U9.14 (B4), U10.16 (D4), U12.5 (D3)
/vga/GD5: U9.13 (B5), U10.17 (D5), U12.4 (D2)
/vga/GD6: U9.12 (B6), U10.18 (D6), U12.3 (D1)
/vga/GD7: U9.11 (B7), U10.19 (D7), U12.2 (D0)
/vga/HSYNC: R2.1, U13.7 (Q2)
/vga/ROW0: U5.36 (M9), U14.10 (A0)
/vga/ROW1: U5.35 (M10), U14.9 (A1)
/vga/ROW2: U5.34 (M11), U14.8 (A2)
/vga/ROW3: U5.33 (M12), U6.18 (1Y0), U10.3 (A7)
/vga/ROW4: U5.29 (M13), U6.16 (1Y1), U10.25 (A8)
/vga/ROW5: U5.28 (M14), U6.14 (1Y2), U10.24 (A9)
/vga/ROW6: U5.27 (M15), U6.12 (1Y3), U10.21 (A10)
/vga/ROW7: U5.26 (M16), U6.3 (2Y0), U10.23 (A11)
/vga/ROW8: U5.25 (M17), U6.5 (2Y1), U10.2 (A12)
/vga/VSYNC: R1.1, U13.5 (Q1)
/vga/~LOAD: U13.10 (Q3), U15.15 (PE)
GND: C2.1, C3.1, C4.2, C5.2, C6.2, C7.2, C8.2, C9.2, C10.2, C11.2, C12.2, C13.2, C14.2, C15.2, C16.2, C17.2, C18.2, C19.2, C20.2, C21.2, C22.2, C23.2, C24.2, C25.2, C26.2, C30.1, C31.1, C32.2, C33.2, C34.2, C35.2, C36.2, C37.2, C38.1, C39.1, C40.2, C41.2, C42.2, C43.2, C44.2, C45.2, C46.2, C47.2, C48.2, C52.2, C53.2, C54.2, C55.2, C56.2, C57.2, C58.2, C59.2, C60.2, C61.2, C62.2, C63.2, C64.2, C65.2, C66.2, C67.2, C68.2, C69.2, C70.2, C71.2, C72.2, D2.1 (K), IC1.1 (VSS_1), IC1.2 (VSS_2), IC1.18 (VSS_3), IC1.36 (VSS_4), J1.1, J1.5, J1.7, J1.11, J1.13, J1.15, J1.19, J1.21, J1.23, J1.25, J1.29, J1.31, J2.0 (PAD), J2.12, J2.25, J3.0, J3.5, J3.6, J3.7, J3.8, J3.10, J4.2, J5.2, J6.2, J6.3, J7.0 (PAD), J7.5, J8.A1 (GND), J8.A12 (GND), J8.B1 (GND), J8.B12 (GND), J8.S1 (SHIELD), JTAG1.10, Q2.3 (E), R29.1, R34.2, R35.2, R37.2, RV1.3, SW1.1, U1.9 (GND), U1.12 (GND), U1.16 (GND), U1.21 (GND), U1.27 (IDENT), U1.30 (DRV2), U1.35 (~INVERT), U1.36 (GND), U1.45 (AVSS), U1.50 (GND), U1.54 (GND), U1.59 (GND), U1.65 (GND), U2.11 (GND), U3.6 (Vss), U4.10 (GND), U4.11 (2A3), U5.10 (GND), U5.23 (GND), U5.31 (GND), U6.10 (GND), U6.11 (2A3), U6.13 (2A2), U7.7 (GND), U8.5 (~E1), U8.8 (GND), U9.10 (GND), U10.1 (N/C), U10.14 (GND), U10.20 (~CE1), U11.7 (GND), U12.1 (OE), U12.10 (GND), U13.8 (GND), U14.14 (GND), U14.20 (~CE), U14.22 (~OE), U15.6 (CE), U15.8 (GND), U16.7 (GND), U17.2 (-), U17.4 (GND), U18.1 (GND), U19.8 (GND), U20.2 (P0), U20.3 (R0), U20.4 (P1), U20.5 (R1), U20.7 (R2), U20.9 (R3), U20.10 (GND), U20.12 (R4), U20.14 (R5), U20.16 (R6), U20.18 (R7), U21.10 (GND), U22.10 (GND), U22.11 (2A3), U22.13 (2A2), U22.15 (2A1), U23.7 (GND), U23.12 (D), U25.15 (GND), U26.3 (GND), U27.7 (GND), U27.9, U27.10, U27.12, U27.13, U28.16 (VSS), U29.14 (GND), U30.7 (GND), U40.16 (VSS), X1.7 (GND)
unnamed: C27.1, C28.1, U17.5
unnamed: C27.2, R29.2
unnamed: C29.1, RV1.2
unnamed: D1.2 (A), R38.2
unnamed: D2.2 (A), R39.2
unnamed: IC1.50 (CKA0/~DREQ0), RN2.3 (R2)
unnamed: C39.2, IC1.4 (EXTAL), Y2.2
unnamed: C38.2, IC1.3 (XTAL), Y2.1
unnamed: IC1.7 (~BUSREQ), RN2.4 (R3)
unnamed: IC1.58 (~DREQ1), RN2.2 (R1)
unnamed: IC1.12 (~INT2), RN2.6 (R5), U23.9 (Q)
unnamed: IC1.63 (~MREQ), U20.1 (G), U21.1 (G), U27.4
unnamed: J1.2, U1.49 (DENSEL)
unnamed: J1.6, U1.28 (DRATE0)
unnamed: J1.8, RN1.2 (R1), U1.26 (INDX)
unnamed: J1.10, U1.57 (ME0)
unnamed: J1.12, U1.62 (DS1)
unnamed: J1.14, U1.58 (DS0)
unnamed: J1.16, U1.61 (ME1)
unnamed: J1.18, U1.56 (DIR)
unnamed: J1.20, U1.55 (STEP)
unnamed: J1.22, U1.53 (WRDATA)
unnamed: J1.24, U1.52 (WE)
unnamed: J1.26, RN1.3 (R2), U1.2 (TRK0)
unnamed: J1.28, RN1.4 (R3), U1.1 (WP)
unnamed: J1.30, RN1.5 (R4), U1.41 (RDDATA)
unnamed: J1.32, U1.51 (HDSEL)
unnamed: J1.34, RN1.6 (R5), U1.31 (DSKCHG)
unnamed: F1.1, J2.1, J2.13, J2.14
unnamed: J2.15, R6.2
unnamed: J2.16, R7.2
unnamed: J2.17, R8.2
unnamed: J2.18, R9.2
unnamed: J2.19, R10.2
unnamed: J2.20, R11.2
unnamed: J2.21, R12.2
unnamed: J2.22, R13.2
unnamed: J2.23, R14.2
unnamed: J2.24, R15.2
unnamed: J2.2, R16.2
unnamed: J2.3, R20.2
unnamed: J2.4, R24.2
unnamed: J2.5, R17.2
unnamed: J2.6, R21.2
unnamed: J2.7, R25.2
unnamed: J2.8, R18.2
unnamed: J2.9, R22.2
unnamed: J2.10, R19.2
unnamed: J2.11, R23.2
unnamed: J3.1, R5.2
unnamed: J3.2, R4.2
unnamed: J3.3, R3.2
unnamed: J3.13, R2.2
unnamed: J3.14, R1.2
unnamed: C28.2, J4.1
unnamed: J5.4, U22.2 (1A0)
unnamed: J5.6, U22.4 (1A1)
unnamed: J5.8, U22.6 (1A2)
unnamed: J5.10, U22.8 (1A3)
unnamed: J5.12, U22.17 (2A0)
unnamed: J8.A5 (CC1), R35.1
unnamed: J8.B5 (CC2), R34.1
unnamed: JTAG1.1, U5.17 (TCK)
unnamed: JTAG1.3, U5.30 (TDO)
unnamed: JTAG1.5, U5.16 (TMS)
unnamed: JTAG1.9, U5.15 (TDI)
unnamed: Q1.2 (B), U7.10
unnamed: Q1.3 (E), R3.1, R4.1, R5.1
unnamed: R26.2, R27.2, R28.2, RV1.1
unnamed: C1.2, U1.38 (HIFIL)
unnamed: C1.1, U1.37 (LOFIL)
unnamed: C3.2, U1.33 (X1), Y1.1
unnamed: C2.2, U1.34 (X2), Y1.2
unnamed: R14.1, U2.18 (ARDY)
unnamed: R19.1, U2.21 (BRDY)
unnamed: R6.1, U2.15 (PA0)
unnamed: R7.1, U2.14 (PA1)
unnamed: R8.1, U2.13 (PA2)
unnamed: R9.1, U2.12 (PA3)
unnamed: R10.1, U2.10 (PA4)
unnamed: R11.1, U2.9 (PA5)
unnamed: R12.1, U2.8 (PA6)
unnamed: R13.1, U2.7 (PA7)
unnamed: R16.1, U2.27 (PB0)
unnamed: R20.1, U2.28 (PB1)
unnamed: R24.1, U2.29 (PB2)
unnamed: R17.1, U2.30 (PB3)
unnamed: R21.1, U2.31 (PB4)
unnamed: R25.1, U2.32 (PB5)
unnamed: R18.1, U2.33 (PB6)
unnamed: R22.1, U2.34 (PB7)
unnamed: R15.1, U2.16 (~ASTB)
unnamed: R23.1, U2.17 (~BSTB)
unnamed: U3.20 (BC1), U11.13
unnamed: U3.18 (BDIR), U11.1
unnamed: R26.1, U3.5 (ch_A)
unnamed: R27.1, U3.4 (ch_B)
unnamed: R28.1, U3.1 (ch_C)
unnamed: U5.37 (M8), U7.13
unnamed: U7.1, U7.5, U7.6, U10.22 (~OE)
unnamed: U7.4, U10.27 (~WR)
unnamed: U11.4, U11.8, U11.9
unnamed: U11.10, U11.11
unnamed: U11.12, U16.6
unnamed: U12.19 (Q0), U14.21 (A10)
unnamed: U12.18 (Q1), U14.24 (A9)
unnamed: U12.17 (Q2), U14.25 (A8)
unnamed: U12.16 (Q3), U14.3 (A7)
unnamed: U12.15 (Q4), U14.4 (A6)
unnamed: U12.14 (Q5), U14.5 (A5)
unnamed: U12.13 (Q6), U14.6 (A4)
unnamed: U12.12 (Q7), U14.7 (A3)
unnamed: U5.3 (M2), U13.3 (D0)
unnamed: U5.1 (M1), U13.4 (D1)
unnamed: U5.2 (M1), U13.6 (D2)
unnamed: U5.4 (M4), U13.11 (D3)
unnamed: U14.11 (D0), U15.2 (A)
unnamed: U14.12 (D1), U15.3 (B)
unnamed: U14.13 (D2), U15.4 (C)
unnamed: U14.15 (D3), U15.5 (D)
unnamed: U14.16 (D4), U15.10 (E)
unnamed: U14.17 (D5), U15.11 (F)
unnamed: U14.18 (D6), U15.12 (G)
unnamed: U14.19 (D7), U15.14 (H)
unnamed: U7.9, U15.13 (Qh)
unnamed: U16.3, U16.4, U16.5
unnamed: U16.8, U27.5
unnamed: C29.2, U17.3 (+)
unnamed: C33.1, U18.5 (CV)
unnamed: C34.1, R31.2, U18.6 (THR), U18.7 (DIS)
unnamed: R32.1, U18.3 (Q)
unnamed: C32.1, R30.2, SW1.2, U18.2 (TR)
unnamed: U20.19 (P=R), U27.1
unnamed: U23.5 (Q), U27.2
unnamed: C51.1, U25.1 (C1+)
unnamed: C51.2, U25.3 (C1-)
unnamed: C49.1, U25.4 (C2+)
unnamed: C49.2, U25.5 (C2-)
unnamed: J7.2, U25.13 (R1IN)
unnamed: J7.8, U25.8 (R2IN)
unnamed: J7.3, U25.14 (T1OUT)
unnamed: J7.7, U25.7 (T2OUT)
unnamed: C50.1, U25.2 (VS+)
unnamed: C50.2, U25.6 (VS-)
unnamed: J8.A6 (D+), J8.B6 (D+), U26.1 (UD+)
unnamed: J8.A7 (D-), J8.B7 (D-), U26.2 (UD-)
unnamed: C52.1, U26.8 (V3)
unnamed: U28.22 (CE#), U30.8
unnamed: U30.3, U30.4
unnamed: U30.5, U30.9, U30.11
unnamed: U30.6, U40.22 (CE#)
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

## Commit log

2024-08-18 HW: Floppy, VGA, PIO and sound
    [floppy.kicad_sch, pio.kicad_sch, sound.kicad_sch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]
2024-08-19 HW: Further work on schematic
    [clock.kicad_sch, cpu.kicad_sch, floppy.kicad_sch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]
2024-08-19 HW: Add memory, serial and power
    [cpu.kicad_sch, floppy.kicad_sch, memory.kicad_sch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]
2024-08-20 HW: Before abandoning DRAM
    [cpu.kicad_sch, floppy.kicad_sch, memory.kicad_sch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]
2024-08-20 HW: Change RAM to static
    [cpu.kicad_sch, floppy.kicad_sch, memory.kicad_sch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]
2024-08-20 HW: PCB complete
    [cpu.kicad_sch, floppy.kicad_sch, memory.kicad_sch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]
2024-08-20 HW: PCB finishing touches
2024-08-20 HW: Fix RST line
    [clock.kicad_sch]
2024-08-20 HW: Revision A
    [bom.csv, designators.csv, positions.csv]
2025-02-12 FW: start work on drivers
    [bom.csv, clock.kicad_sch, cpu.kicad_sch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]
2025-02-12 HW: Fix UART1 having RX and TX swapped
    [bom.csv, designators.csv, positions.csv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]
2025-02-12 Update README and issues
    [bom.csv, designators.csv, positions.csv]
2025-02-12 HW: Fix bug in I/O decoder
    [cpu.kicad_sch]
2025-02-12 Drivers: Add makefile, fix AY-3-8912
2025-02-12 driver: Start work on floppy controller driver
2025-02-12 schematic: Fix incorrect information about 82077 mode
    [floppy.kicad_sch]
2025-02-12 driver: working floppy sector read
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2025-02-12 driver/floppy: improve error handling
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2025-02-12 driver/floppy: Working read and write
2025-02-12 driver/floppy: Rename lower layer, working access to the whole disk
2025-02-12 driver: add PIO driver
2025-02-12 driver/floppy: add floppy interface wrapers
2025-02-12 driver/floppy: remove redundant seek
2025-02-12 driver/floppy: optimize FIFO read/write, add timeout
2025-02-12 driver/floppy: fix buggy retval check
2025-02-12 driver/floppy: Fix build, use asm local labels
2025-02-12 driver/floppy: add comment about not working eject detection, change delay
2025-02-12 driver/floppy: remove explicit RET
2025-02-12 driver/floppy: Fix write regression
2025-02-12 HW: remove unnecessary kicad files
2025-02-12 FW: Add interrupts handling in bootloader
2025-02-12 driver: start work on VGA
2025-02-12 vga: mostly working vga driver
2025-02-12 HW: Fix A0 of AY-3-8912 being connected to D0 instead of A0
    [cpu.kicad_sch, pio.kicad_sch, sound.kicad_sch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]
2025-02-12 Update schematic pdf file
2025-02-12 Add devkit STL model
    [dev.FCStd, dev.stl]
2025-02-12 HW: Fix address and data buses being swapped for keyboard connector
    [zak180.kicad_sch]
2025-02-12 HW: update schematic pdf
2025-02-12 HW: Connect 82077 /DREQ to the Z180 DMA ch 1, PCB decorations
    Rev B done
    [bom.csv, cpu.kicad_sch, designators.csv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]
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2025-02-12 UART: Fix warning
2025-02-12 kernel: working systick timer
2025-02-12 kernel: start work on threads
2025-02-12 kernel: working thread sleep
2025-02-12 kernel/proc: fix incorrect version of timer_get being used
2025-02-12 VGA: guard against cursor handling in the interrupt
2025-02-12 HW: Fix unconnected /SOUND net, add /RST header and /DTR power supply
    [clock.kicad_sch, cpu.kicad_sch, floppy.kicad_sch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]
2025-02-12 HW: revision C
    [bom.csv, designators.csv, positions.csv]
2025-02-12 HW: remove rev A gerbers
    [bom.csv, designators.csv, positions.csv]
2025-02-12 HW: add ESP32 dongle
    [ESP8266.kicad_pcb, ESP8266.kicad_sch, bom.csv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]
2025-02-12 driver: compile all drivers to the single lib
2025-02-12 FAT: start work on a'la vfs FAT implementation (WIP)
2025-02-12 kernel: define block device API + floopy blk
2025-02-12 vfs: improve API, mount implementation
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2025-02-12 3D: add case 3D model (FreeCAD + STL)
    [bottom.FCStd, bottom.stl, case.FCStd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]
2025-02-12 3D: improve case model
    [case.FCStd, case.stl]
2025-02-12 3D/case: add vent holes, move PCB to clear IO plugs
    [case.FCStd, case.stl]
2025-02-12 3D: fix bottom no longer matching case, move it to the one FreeCAD file
    [bottom.FCStd, bottom.stl, case.FCStd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]
2025-02-12 fs: fix mount regression
2025-02-12 fat: refactor truncate to generalise FAT chain trimming
    Fix bugs:
    - truncate in some cases hasn't been zeroing whole space,
    - fat_sync did nothing
2025-02-12 3d: add keyboard support bar model
    [keyboard_support.FCStd, keyboard_support.stl]
2025-02-12 proc: fix thread_yield hogging interrupts
2025-02-12 proc: remove initial thread id allocator
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2025-02-12 proc: add thread and process ending (WIP, not tested)
2025-02-12 driver: move DMA to shared module from VGA
2025-02-12 proc: WIP add process_fork() implementation (not tested yet)
    REGRESION: process_start will not work anymore - had to remove CONTEXT_LAYOUT_USER from the thread_create.
    Plans for vfork has been replaced with fork. vfork is a whole headache of edge-cases that would both tedious to handle correctly and cost code space. fork() on the other hand require memory map to be copied (no hope of COW on this target). I deciced I rather do this copying (quickly, via DMA).
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2025-02-12 kernel: replace printf() with kprintf(), prepare to ditch SDCC printf implementation
2025-02-13 lib: add lightweight kprintf, replace SDCC printf
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2025-02-14 proc: fix thread not being removed from id_storage on join
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2025-04-01 usr: remove bye app, replace test with uart echo
2025-04-01 uart: clear errors - fix broken uart on overrun
    fix wrong rd pointer update on fifo overwrite
2025-04-01 proc: add mechanism to signal threads from irq handler
2025-04-01 uart: move irq based driver to the kernel devfs
    Use polling for kernel messages for now.
    Remove CPU hogging - add wait/signal on block.
2025-04-03 hello: replace uart test with stdin/stdout one
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2025-04-03 threads: no need to restore memory bank in scheduler
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2025-04-27 3d: new case model with better keyboard support
    [bottom.stl, case.FCStd, case.stl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]
2025-06-15 Initial import from ZAK180
    [bom.csv, bottom.stl, case.FCStd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]
2025-06-15 hw: simplify logic, replace some SSI with GALs
    [clock.kicad_sch, cpu.kicad_sch, floppy.kicad_sch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]
2025-06-17 hw: adapt to the changes in memory decoder pinout
    [cpu.kicad_sch, sound.kicad_sch]
2025-06-17 hw: color text mode VGA (WIP)
    [cpu.kicad_sch, sound.kicad_sch, vga.kicad_sch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]
2025-06-18 hw: change user port footprint (less offset)
    [pio.kicad_sch]
2025-06-19 hw: finish schematic, start routing
    [cf.kicad_sch, clock.kicad_sch, cpu.kicad_sch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]
2025-06-19 hw: continue routing
    [zak181.kicad_pcb]
2025-06-19 hw: finish routing
    [cf.kicad_sch, keyboard.kicad_sch, memory.kicad_sch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]
2025-06-19 hw: connect VA14 to GND
    [vga.kicad_sch]
2025-06-19 hw: add production files
    [bom.csv, designators.csv, positions.csv]
2025-06-20 hw: make AY-3-8912 decoder equations more readable
    [sound.kicad_sch]
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2025-06-20 hw: add missing shload_n connection
    [cf.kicad_sch, clock.kicad_sch, cpu.kicad_sch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]
2025-06-21 hw: replace CPLD JTAG connector, minor fixes
    [bom.csv, designators.csv, positions.csv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]
2025-07-02 hw: add note about CF footprint
    [cf.kicad_sch]
2025-07-02 hw: fix hsync/vsync being connected to wrong pins
    [positions.csv, vga.kicad_sch, zak181.kicad_pcb]
2025-07-02 pld/z181md: remove dependency on A13, allow access to whore VRAM
    [cpu.kicad_sch]
2025-07-02 hw/vga: reduce resistance in DAC to impove image sharpness
    [vga_datapath.kicad_sch, zak181.kicad_pcb]
2025-07-02 hw: add RC to /RD for CF for increased compatibility
    [cf.kicad_sch, cpu.kicad_sch, sound.kicad_sch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]
2025-07-06 hw: rev B
    [bom.csv, cf.kicad_sch, clock.kicad_sch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]
2025-07-20 Fix wrong D-SUB footprints, rev C
    [bom.csv, cf.kicad_sch, clock.kicad_sch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]
2025-07-27 3d: add case model
    [case-Bottom.stl, case-Top.stl, case.FCStd]
2025-07-28 3d: add side skirts to the top of the case
    [case-Bottom.stl, case-Top.stl, case.FCStd]
2025-07-29 3d: Add ridge to the top of the case to interface with the bottom
    [case-Top.stl, case.FCStd]
2025-08-02 rev D
    - Fix SUB-D footprints yet again,
    - rotate keyboard connector to remove cable twist,
    - add onboard speaker.
    [bom.csv, cf.kicad_sch, clock.kicad_sch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]
2025-08-04 3d: add auxiliary I/O board to the case
    [bom.csv, case-Bottom.stl, case.FCStd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]
2025-08-14 Rev E: fix MAX232 usage
    [bom.csv, cf.kicad_sch, clock.kicad_sch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]
2025-08-17 hw: rotate keyboard connector, move reset connector
    - previous keyboard connector rotatation was indeed good already
    - move reset connector to remove interference with the keyboard
    [positions.csv, zak181.kicad_pcb]
2025-08-17 3d: add bottom case with cutout for emuprom cable
    [case-Bottom-debug.stl, case-debug.FCStd]
